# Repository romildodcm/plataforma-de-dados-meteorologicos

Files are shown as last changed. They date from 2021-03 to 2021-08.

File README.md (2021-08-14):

# PLATAFORMA DE DADOS METEOROLÓGICOS
Esse projeto tem por objetivo o desenvolvimento de uma plataforma de dados meteorológicos composta por estações meteorológicas, banco de dados e interface gráfica para análise e monitoramento. Espera-se com esse trabalho formar uma base de dados que permitirá a elaboração de estudos e previsão de geração de energia solar que podem ser aplicados para verificar a viabilidade de instalação de usinas solares, essa plataforma também poderá ser instalada junto de uma unidade geradora para auxiliar no monitoramento de geração, previsões e auxílio na tomada de decisões. Por se tratar de um projeto open source, almeja-se também contribuir com a redução de obstáculos e custos para disseminação e divulgação tecnológica desse tipo de tecnologia.

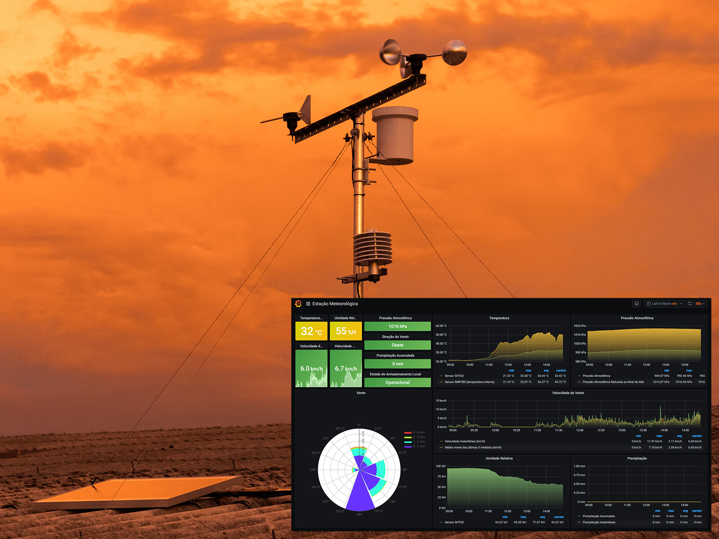
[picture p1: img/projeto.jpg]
Projeto


## ESTAÇÃO METEOROLÓGICA
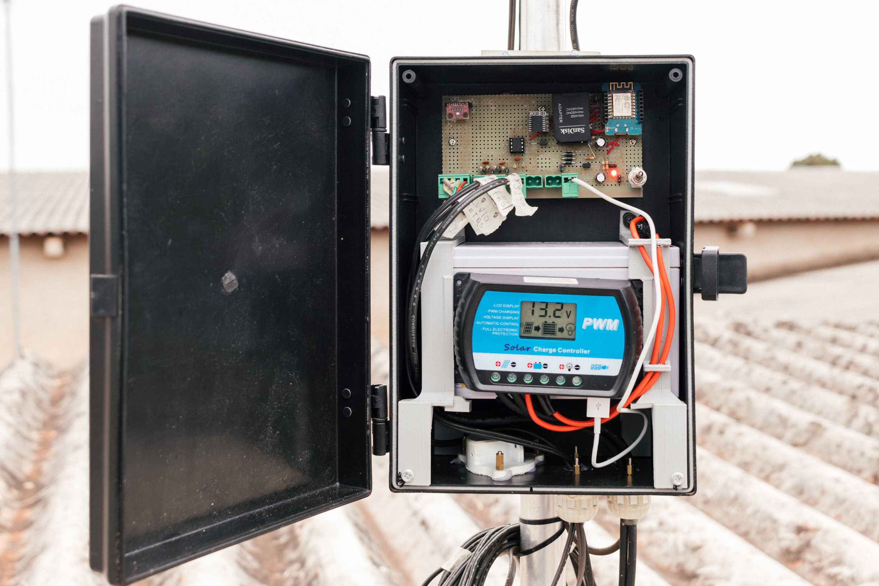
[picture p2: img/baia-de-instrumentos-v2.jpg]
Baia de instrumentação

Seguindo os conceitos de sensor autônomo e internet das coisas (IoT), foi projetada e construída uma estação meteorológica com microcontrolador ESP8266, programado em C/C++® no ambiente Arduino®, e inicialmente com os sensores de direção do vento, temperatura, umidade, pressão, pluviômetro e anemômetro, posteriormente serão implementados sensores de radiação solar direta e global, através de comunicação serial também é possível a implementação de sensores para monitorar a geração de energia, a estação processa os dados desses sensores, envia para internet através de conexão Wi-Fi® e também armazena localmente em cartão de memória.

Os esquemas elétricos para montagem da estação podem ser acessados no diretório *esquema-eletrico* e os códigos para os microcontroladores estão no diretório *software*, no projeto o circuito foi confeccionado usando uma placa ilhada, abaixo estão as tabelas com materiais necessários, esses sistemas foram integrados e montados na estrutura da estação, como pode ser visto nas imagens, os arquivos com as peças e montagem com o programa *Inventor* estão no diretório *estruturas*, também devem ser inseridos em breve os arquivos do projeto/desenhos técnicos em outros formatos.

Tabela 1: Lista de componentes eletrônicos e alojamentos da Estação Meteorológica.
Quantidade | Componente | Valor unitário (R$)
------------ | ------------- | -------------
1 | Bateria Estacionária 7Ah | 109,90
1 | Painel Solar Fotovoltaico 30W | 189,00
1 | Controlador de Carga RTD1230 30A 12/24V | 170,00
2 | Conector MC4 Painel Solar | 10,00
2 | Metro cabo 4 mm² | 5,00
1 | Metro fio 2,5 mm² flexível | 2,00
3 | Metro Cabo flexível 26 AWG | 0,37
1 | Caixa Plástica PB-255/2 | 79,90
1 | Pluviômetro | 344,61
1 | Indicador de direção do vento | 284,63
1 | Anemômetro | 263,970
1 | Sensor de temperatura e umidade SHT20 | 297,23
1 | Alojamento para sensor e temperatura e umidade | 250,74
1 | RTC DS3231 | 22,50
1 | Sensor de pressão e temperatura BMP280 | 14,90
4 | Diodo 1N4007 | 0,10
4 | Borne Conector F 2EDGK-5,0 - 2 Vias | 1,99
1 | Borne Conector F 2EDGK-5,0 - 4 Vias | 3,70
4 | Borne Conector M 2EDGVC-5,0 4P 180º | 1,75
1 | Wemos ESP8266 | 50,00
1 | ATtiny85 DIP8 | 17,00
1 | Soquete DIP8 | 3,00
1 | Mini chave HH Alavanca SMTS102 2 Posições | 2,70
1 | Barra de Pinos 40 vias 11,2mm 180 graus | 1,00
1 | Barra de soquete header fêmea 40 vias 180 graus | 1,65
1 | Cartão microSD com adaptador SD 8GB | 29,9
2 | Capacitor eletrolítico 470uF | 0,50
5 | Capacitor cerâmico 100nF | 0,10
1 | Resistor 220 Ohm 1/4W | 0,10
2 | Resistor 330 Ohm 1/4W | 0,10
2 | Resistor 1k Ohm 1/4W | 0,10
1 | Resistor 10k Ohm 1/4W | 0,10
1 | Resistor 47k Ohm 1/4W | 0,10
1 | Placa padrão tipo ilha 10x15 mm | 14,00
1 | Peças impressas em 3D | 50,00

Tabela 2: Lista de componentes da estrutura da estação meteorológica*.
Quantidade | Componente | Valor unitário (R$)
------------ | ------------- | -------------
1 | 2,5m Tubo redondo alumínio 1.1/4" X 1/16" (31,75mm X 1,58mm) | 39,00
1 | 3m Tubo quadrado alumínio 3/4 X 1/16 (1,9cm X 1,58mm) | 25,00
1 | Chapa de aço 2mmx80x60mm | 5,00
1 | Haste De Cobre Puro 10 mm X 500 mm | 50,00
1 | Borracha espessura 1x80x20mm | 5,00
3 | Espaçador m3 x 15mm | 0,30
7 | Parafuso m3 x 15mm | 0,12
7 | Parafuso m3 x 6mm | 0,10
1 | Parafuso m5 x 16mm | 0,20
2 | Barra roscada 1/4 x 100mm | 2,50
2 | Parafuso sextavado 1/4 x 16mm | 0,30
2 | Parafuso sextavado 1/4 x 30mm | 0,30
24 | Porca sextavada 1/4 | 0,10
20 | Ruela de metal m6 ou 1/4| 0,15
2 | Ruela de metal m3 | 0,10
4 | Ruela de borracha m6 ou 1/4 | 0,25
2 | Anel de borracha m6 | 0,15
6 | Abraçadeira U Vergalhão bitola 1 polegada 80mm rosca 1 quarto (Part. 0070.1) | 6,00
4 | Abraçadeira suporte (Part. 0070.2) | 4,10

***Observações**:
* Na lista e no projeto não estão inclusos estrutura para fixação do painel solar, essa pode ser construída ou comprada, variando de acordo com o tipo de instalação, como pode ser visto na imagem, aqui ela foi fixada em uma cantoneira metálica e essa foi parafusada sobre a cobertura da casa;
* Essa lista é uma base que bate com o projeto disponibilizado no diretório de *estruturas*, podendo/devendo ser alterado em função do local de instalação e conforme os sensores que serão implementados, como se pode notar ao comparar a estação do projeto e a que foi montada, como a que está construída está sobre uma casa onde não precisa de para-raios (já tem em outra estrutura nas proximidades), e também ainda não foram implementados sensores solares, então a estrutura ficou mais simples, para economizar, também podem construir utilizando sucatas;
* Como pode ser visto na imagem a seguir, à esquerda o número 1 indica haste adicionada ao projeto para instalação de sensores solares, na estação construída (à direita) não tem essa haste pois esses sensores ainda não ficaram prontos para serem implementados. Outro detalhe são o uso das barras roscadas que aparecem no projeto e na estação montada, elas servem para prender e regular os fios que fixam e mantem o posicionamento da estação.

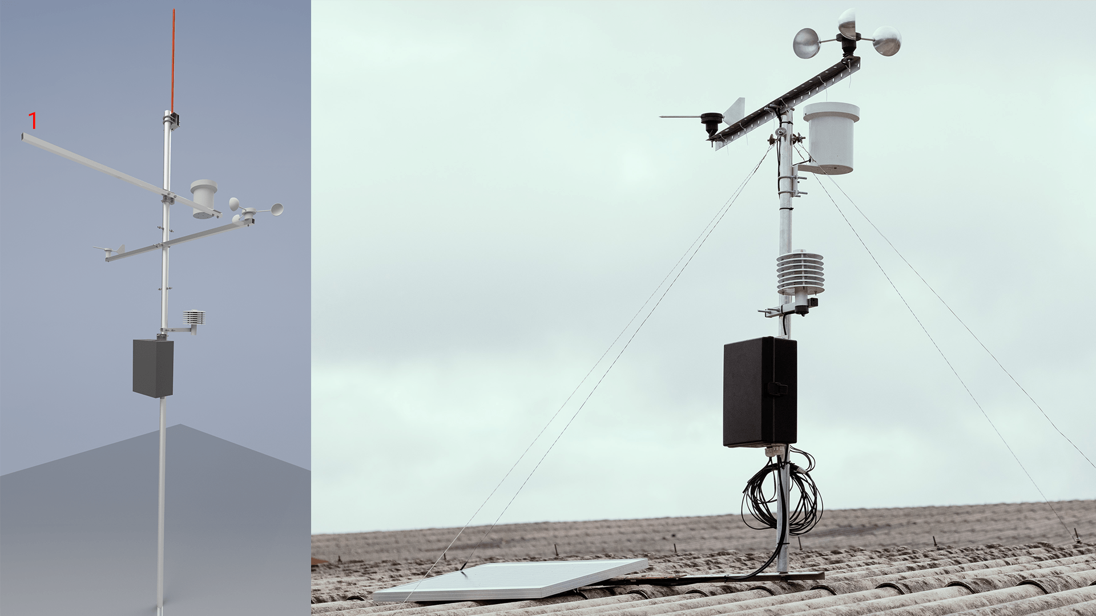
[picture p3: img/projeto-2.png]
Projeto


## BANCO DE DADOS E INTERFACE GRÁFICA

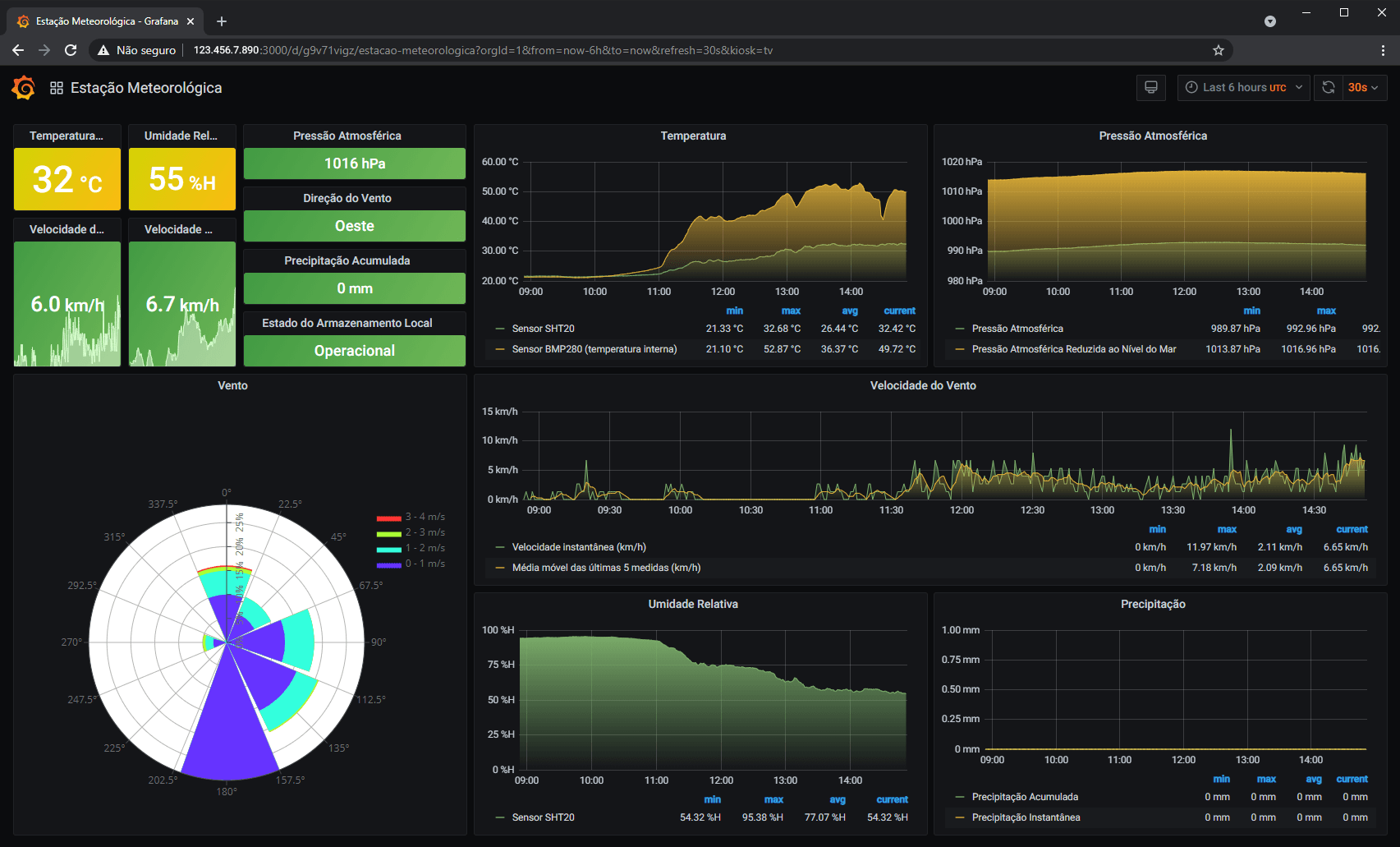
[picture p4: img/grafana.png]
Dashboard Grafana


O banco de dados e a interface de usuário foram implementados em um Raspberry Pi® utilizado como servidor, onde um algoritmo em Python® faz o recebimento e processamento dos dados que são colocados em banco InfluxDB®, nesse servidor foi implementada com Grafana® uma interface gráfica que é acessada por usuários através de um navegador web, sendo apresentados os parâmetros atualizados e séries temporais, como mostra a figura acima. No diretório *weather-station-server-side* é possível ver o script implementado e a documentação que apresenta como fazer a implementação dessa parte do projeto.

Tabela 3: Lista de Materiais para o Servidor.
Quantidade | Componente | Valor unitário (R$)
------------ | ------------- | -------------
1 | Raspberry Pi 4 Model B 4GB | 640,00
1 | Fonte para Raspberry Pi 4 | 65,00
1 | Cartão de memória classe 10 16GB | 60,00

## Descrição das Medidas/Parâmetros/Dados
Para os códigos e hardware dessa versão da estação (v2), temos a estação armazenando localmente, em um arquivo por dia, em horário UTC, a seguinte string com dados separados por vírgula (CSV):

    20210811155149,37.17,99830.05,19.43,63.45,E,3.99,1.00,snr,snr

Contendo 10 parâmetros, sendo 1 de tempo e 9 medidas, após armazenar localmente esses parâmetros, a estação meteorológica concatena um parâmetro a mais que é o status da gravação local, um número inteiro que pode ser 1, 2 ou 3, que respectivamente significam "ok, armazenamento local operacional", "não conseguiu iniciar o cartão de memória e consequentemente não armazenou os dados localmente", "iniciou o cartão de memória, mas não conseguiu armazenar os dados". A string com 11 dados separados por vírgula e transmitida por MQTT é como o exemplo a seguir:

    20210811155149,37.17,99830.05,19.43,63.45,E,3.99,1.00,snr,snr,1

Tabela 1: Descrição dos dados.
Dado | Microcontrolador | Sensor | Posição no CSV | Nome no banco de dados | Tipo no banco de dados | Unidade de medida no CSV | Unidade de medida no Banco de dados | Observação
------------ | ------------- | ------------- | ------------- | ------------- | ------------- | ------------- | ------------- | -------------
Data e Horário da medida | ESP8266 | ---- | 1 | ---- | ---- | ---- | ---- | No CSV está no formato AAAAMMDDhhmmss*
Temperatura | ESP8266 | BMP280 | 2 | temperature_bmp | float | °C | °C | ----
Pressão | ESP8266 | BMP280 | 3 | pressure_bmp | float | Pa | hPa | ----
Temperatura | ESP8266 | SHT20 | 4 | temperature_sht | float | °C | °C | ----
Umidade | ESP8266 | SHT20 | 5 | humidity_sht | float | %H | %H | ----
Direção do Vento | ATtiny85 | Wind Vane | 6 | wind_direction | int | Direção em ponto cardeal | Direção em graus | ----
Velocidade do vento | ATtiny85 | Anemômetro | 7 | anemometer | float | Km/h | Km/h | ----
Precipitação | ATtiny85 | Pluviômetro | 8 | pluviometer_raw | float | mm | mm | ----
Sensor Solar 1 | ATtiny85 Solar | ---- | 9 | serial_sensor1 | int | ---- | ---- | ----
Sensor Solar 2 | ATtiny85 Solar | ---- | 10 | serial_sensor2 | int | ---- | ---- | ----
Status memória SD | ESP8266 | ---- | 11 | sd_memory_status | int | ---- | ---- | 1 = Ok, 2 = erro em SD begin, 3 = erro na escrita de dados

\* **Descrição do formato de data e horário no CSV**
AAAA = ano, quatro dígitos
MM = mês, dois dígitos
DD = dia, dois dígitos
hh = hora, dois dígitos 0 até 24
mm = minutos, dois dígitos
ss = segundos, dois dígitos

\* **Serial Not Received ("snr")**
Quanto o ESP8266 solicita os dados e eles não são recebidos ou chegam danificados, então é retornado esse valor ```snr```, e quando esse valor chega no script em Python, ele é interpretado como null, portanto não é armazenado essa medida no banco de dados.

## Recomendações para futuras implementações
#### API para acesso aos dados
Hoje o acesso aos dados pode ser feito acessando diretamente o banco de dados InfluxDB ou via Grafana, mas seria interessante posteriormente ser desenvolvida uma API onde sejam cadastrados usuários e esses cadastrados possam fazer o acesso aos dados dentro de parâmetros específicos, etc, permitindo automação do processamento de dados ou estudos com scripts.

#### Interface gráfica publica
Se tiver servidor/VPS pode ser implementada alguma interface, página web, aberta em que as pessoas possam acessar e visualizar os dados, por exemplo, das últimas 24h, talvez isso pode ser feito com Grafana, tornando o acesso para visualização público, ou deixando publico um usuário e senha sem permissões administrativas, para apenas visualização ou tentar as opções de [share a dashboard](https://grafana.com/docs/grafana/latest/sharing/share-dashboard/).

#### Segurança
**Implementar Backup** das informações que hoje estão no cartão de memória do Raspberry Pi, que se queimar, todas as informações são perdidas.
Implementar **recursos de segurança** como HTTPs, criptografias e demais recursos que algum profissional da área ou usuário possam recomendar.

#### Sleep Time no ESP8266

No final do código esp8266.ino tem uma linha com a seguinte operação: ```sleep_time = abs(59000 - sleep_time);```, é recomendado, para evitar passar o limite de tráfego do MQTT em possível sincronização das estações,  variar o valor do ```59000``` para cada estação adicionada, para a estação 1 foi deixado em ```60000```, a estação 2 em ```59000```.

## EQUIPE E CONTATO

Esse projeto foi desenvolvido por Romildo C Marques¹, quando aluno de engenharia física (UNILA), sendo orientado pelo prof. Oswaldo Hideo Ando Junior² (GPEnSE) da Universidade Federal da Integração Latino-Americana (UNILA).

Contato¹: romildodcm@gmail.com
Contato²: oswaldo.junior@unila.edu.br

## APOIO E FOMENTO

Este projeto foi desenvolvido com apoio e fomento de:
* Conselho Nacional de Desenvolvimento Científico e Tecnológico - CNPq;
* Universidade Federal da Integração Latino-Americana (UNILA);
* Grupo de Pesquisa em Energia e Sustentabilidade Energética - GPEnSE;
* Programa Agenda Tríplice da UNILA pelo apoio e fomento à pesquisa.

## AGRADECIMENTOS
Aos amigos e familiares pelo apoio;
Ao professor Oswaldo Hideo Ando Junior pela orientação;
Ao professor Joylan Nunes Maciel por auxíliar com banco de dados;
Ao Lucas Teske (@racerxdl) que apresentou e recomendou as tecnologias InfluxDB e Grafana.



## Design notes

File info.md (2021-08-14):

# Configuração para gravação do ATtiny85

Para a gravação de código no ATtiny85 é necessário remover ele da placa da estação meteorológica e usar um Arduino como placa gravadora, além disso é necessário configurar a IDE Arduino instalando a placa e selecionando as opções corretas antes de enviar o código, abaixo estão as configurações utilizadas e em seguida alguns links de referência.

Configuração da IDE Arduino para compilação e envio de código para ATtiny85
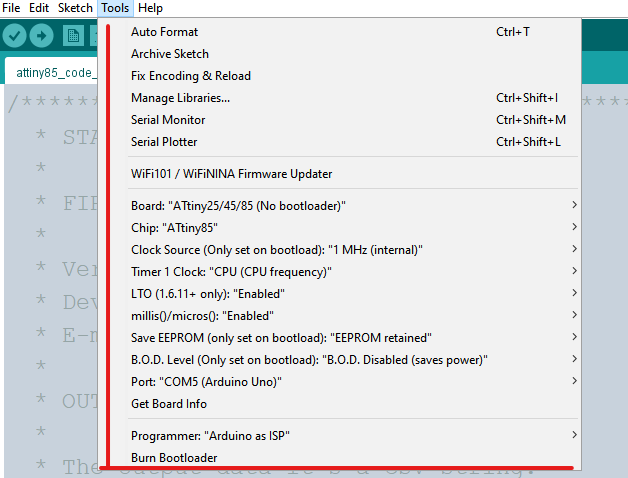
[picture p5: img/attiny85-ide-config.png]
Configuração da IDE para gravação do microcontrolador ATtiny85

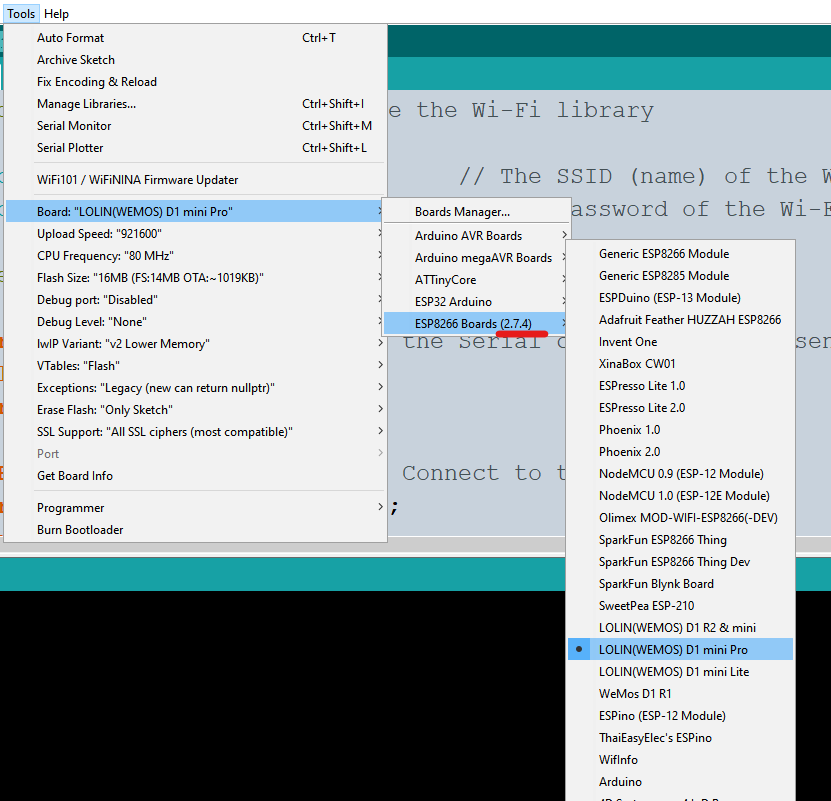
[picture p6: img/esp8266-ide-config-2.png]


[Como Gravar um Attiny85 usando um Arduino Nano](https://youtu.be/0S3D9iLHu5w)
[Programar o ATtiny85 com Arduino: como funciona](https://br-arduino.org/2015/01/programar-o-attiny85-com-arduino-como-funciona.html)
[Como gravar o bootloader do ATtiny85 com Arduino](https://www.arduinoecia.com.br/gravar-bootloader-attiny85-arduino-uno/)

# Configuração para gravação do ESP8266

O ESP8266, usado na estação meteorológica como placa de desenvolvimento WEMOS, para ser programado com IDE Arduino é necessário configurar a IDE instalando a placa e selecionando as opções corretas antes de enviar o código, abaixo estão as configurações utilizadas e em seguida alguns links de referência. Esse código foi compilado tendo a versão 2.7 das placas adicionadas na IDE do Arduino, com versões mais recentes teve erro, na hora da instalação da palca é possível selecionar a versão na IDE Arduino [veja mais](https://www.filipeflop.com/blog/programar-nodemcu-com-ide-arduino/).

Configuração da IDE Arduino para compilação e envio de código para ESP8266 (WEMOS Dev Board)
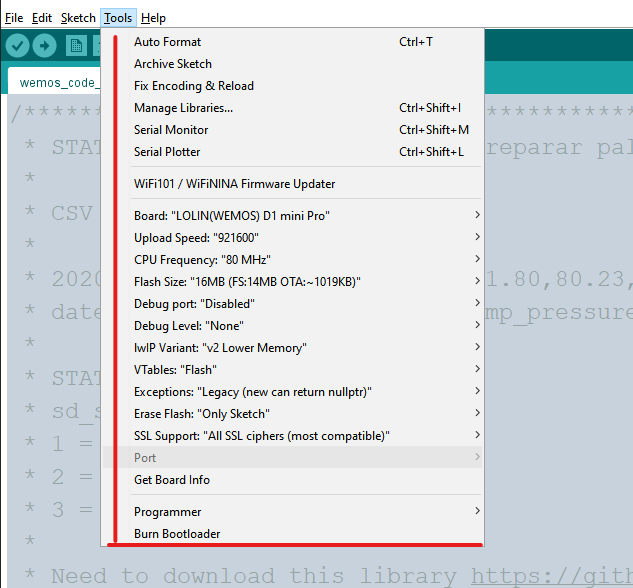
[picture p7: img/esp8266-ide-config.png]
Configuração da IDE para gravação do microcontrolador ESP8266


[Configurar Arduino IDE com ESP8266 e Blynk (HomeLab)](https://edisciplinas.usp.br/pluginfile.php/6231574/mod_resource/content/3/Configurar%20Arduino%20IDE%20com%20ESP8266%20e%20Blynk%20%28HomeLab%29.pdf)
[Conheça o Wemos D1 Mini: pequena no tamanho e imensa nas funcionalidades](https://blogmasterwalkershop.com.br/embarcados/wemos/conheca-wemos-d1-mini)

# Diretórios

Na pasta de hardware tem os projetos em 3D e peças da estação meteorológica, e também projeto de placa controladora e esquema/circuito elétrico, na pasta de software estão os códigos que estão gravados nos microcontroladores das estações meteorológicas. Na pasta attiny85-solar tem um código base para rodas nos microcontroladores dos sensores solares, esse código foi testado com o ATtiny85 conectado na estação e enviando dois números inteiros aleatórios (simulando leitura analógica) para a estação, que recebia esses parâmetros e envia para o servidor.

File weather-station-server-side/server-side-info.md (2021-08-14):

# Configuração Script, InfluxDB e Grafana

## Índice
- [Introdução](#introducao)
- [Configuração de reserva de endereço de IP via DHCP (servidor local)](#ip)
- [Instalação e configuração de banco de dados InfluxDB 1.8](#influx)
- [Instalação e configuração do Grafana](#grafana)
- [MQTT](#MQTT)

## Introdução

Essa parte da plataforma de dados meteorológicos deve ser implementada em servidor, que pode ser desde um Raspberry Pi (a partir da versão 3b) até um serviço VPS, sendo responsável pelas etapas que vão desde a recepção dos dados meteorológicos via MQTT até o armazenamento no banco de dados e disponibilização de interface gráfica ao usuário.

Para a implementação dessa etapa é interessante ter o conhecimento básico de redes, sistemas Unix/Linux, uso de terminal via SSH e linguagem Python, pois as implementações estão divididas em:

- Configuração de reserva de endereço de IP via DHCP (servidor local);
- Instalação e configuração de banco de dados InfluxDB 1.8;
- Configuração de parâmetros para o script Python e Crontab;
- Instalação e configuração do Grafana.

## Configuração de reserva de endereço de IP via DHCP (servidor local)

Ao completar a instalação do banco de dados, o mesmo deverá ser acessado através de um endereço de IP para armazenamento e requisições das informações meteorológicas, se estiver usando um Raspberry Pi em sua rede local, o seu modem pode dar endereços IP aleatórios ao Raspberry, para evitar isso é necessário que identifique o endereço MAC do seu Raspberry Pi, que pode estar na caixa dele ou então pode ser visto usando o comando *ifconfig* no terminal, o Raspberry Pi tem um endereço MAC para o Wi-Fi e outro para a conexão cabeada, então use o endereço MAC do tipo de conexão que estiver sendo utilizada. Com o endereço MAC, acesse a página de configuração de seu modem/roteador e vá até a opção de **DHCP Server** ou nome semelhante, nessa opção procure por **Address Reservation**, **Reserva de Endereço** ou nome semelhante, nessa opção você vai adicionar o endereço MAC do Raspberry Pi e reservar um endereço de IP para ele, reinicie o modem e o Raspberry para implementar a reserva de endereço, anote o IP escolhido, pois ele é um dos parâmetros necessários para o script em Python e também para o Grafana.

## Instalação e configuração de banco de dados InfluxDB 1.8

Esse projeto foi implementado com o banco de dados InfluxDB, para instalar esse banco de dados, acesse https://portal.influxdata.com/downloads/, instale também o influxdb-client com o comando *udo apt install influxdb-client*. Para saber mais sobre o uso do InfluxDB e uma base de como funciona a integração entre Python e InfluxDB, e também sobre a configuração do Grafana, veja a publicação disponível em https://diyi0t.com/visualize-mqtt-data-with-influxdb-and-grafana/, vale lembrar que a instalação do influxDB apresentada nesse segundo link não garante que será a versão 1.8 (necessária para ser compatível com o script python).

Nessa etapa, o nome padrão escolhido para o banco de dados foi **weather_stations_data**, também foi criado um usuário **putdata** para adicionar dados com o script em Python e o **getdata** que será utilizado pelo Grafana para solicitar dados. Caso escolha nomes diferentes, implemente as alterações nas próximas etapas, mudando isso no arquivo [**.env**](./.env) e no **Grafana**.

Para implementar atualizações, gerenciar o banco de dados, etc, verifique a documentação em [InfluxDB OSS 1.8 Documentation](https://docs.influxdata.com/influxdb/v1.8/).

## Configuração de parâmetros para o script Python e Crontab

O script em Python 3 é responsável por receber os dados via MQTT, processar eles e armazenar no banco de dados, para ele ser executado é necessário ter instaladas as bibliotecas que estão citadas nas primeiras linhas de [**script.py**](./script.py) e também ter no mesmo diretório o [**weather_station.py**](./weather_station.py) e o arquivo [**.env**](./.env) com parâmetros de configuração.

Em [**script.py**](./script.py) está o básico do programa, como receber os dados, fazer uma breve verificação e passar para as funções do [**weather_station.py**](./weather_station.py), que farão o resto do processamento e retornarão uma lista de dicionários, compatíveis com o tipo JSON, e esta é enviada para o banco de dados. As senhas, e o endereço de IP do banco de dados no Raspberry Pi/Servidor, credenciais do banco de dado e MQTT devem ser inseridas no arquivo [**.env**](./.env), esses trÊs arquivos estando na mesma pasta, já é possível executar para testes, durante a execução o programa retorna as saídas abaixo:

```
MQTT to InfluxDB script
Connected with result code 0
--------------------------------------------------------------------------------------------------------------------------------
Measurement time: 2021-08-04T14:43:08Z
Weather station: ws01
Message length: 11
Received data: 20210804144308,40.47,100230.45,21.88,44.03,E,2.66,0.00,snr,snr,1
Invalid serial_sensor1: snr => null
Invalid serial_sensor2: snr => null
Writing to database...
{'measurement': 'temperature_bmp', 'tags': {'location': 'ws01'}, 'time': '2021-08-04T14:43:08Z', 'fields': {'value': 40.47}}
{'measurement': 'pressure_bmp', 'tags': {'location': 'ws01'}, 'time': '2021-08-04T14:43:08Z', 'fields': {'value': 1002.3045}}
{'measurement': 'temperature_sht', 'tags': {'location': 'ws01'}, 'time': '2021-08-04T14:43:08Z', 'fields': {'value': 21.88}}
{'measurement': 'humidity_sht', 'tags': {'location': 'ws01'}, 'time': '2021-08-04T14:43:08Z', 'fields': {'value': 44.03}}
{'measurement': 'wind_direction', 'tags': {'location': 'ws01'}, 'time': '2021-08-04T14:43:08Z', 'fields': {'value': 90}}
{'measurement': 'anemometer', 'tags': {'location': 'ws01'}, 'time': '2021-08-04T14:43:08Z', 'fields': {'value': 2.66}}
{'measurement': 'pluviometer_raw', 'tags': {'location': 'ws01'}, 'time': '2021-08-04T14:43:08Z', 'fields': {'value': 0.0}}
{'measurement': 'sd_memory_status', 'tags': {'location': 'ws01'}, 'time': '2021-08-04T14:43:08Z', 'fields': {'value': 1}}
Status write data to Influx Database: True
--------------------------------------------------------------------------------------------------------------------------------
Measurement time: 2021-08-04T14:43:15Z
Weather station: ws_test
Message length: 11
Received data: 20210804144315,36.58,100283.08,31.86,31.66,SE,2.66,1.75,snr,snr,1
Invalid serial_sensor1: snr => null
Invalid serial_sensor2: snr => null
Writing to database...
{'measurement': 'temperature_bmp', 'tags': {'location': 'ws_test'}, 'time': '2021-08-04T14:43:15Z', 'fields': {'value': 36.58}}
{'measurement': 'pressure_bmp', 'tags': {'location': 'ws_test'}, 'time': '2021-08-04T14:43:15Z', 'fields': {'value': 1002.8308}}
{'measurement': 'temperature_sht', 'tags': {'location': 'ws_test'}, 'time': '2021-08-04T14:43:15Z', 'fields': {'value': 31.86}}
{'measurement': 'humidity_sht', 'tags': {'location': 'ws_test'}, 'time': '2021-08-04T14:43:15Z', 'fields': {'value': 31.66}}
{'measurement': 'wind_direction', 'tags': {'location': 'ws_test'}, 'time': '2021-08-04T14:43:15Z', 'fields': {'value': 135}}
{'measurement': 'anemometer', 'tags': {'location': 'ws_test'}, 'time': '2021-08-04T14:43:15Z', 'fields': {'value': 2.66}}
{'measurement': 'pluviometer_raw', 'tags': {'location': 'ws_test'}, 'time': '2021-08-04T14:43:15Z', 'fields': {'value': 1.75}}
{'measurement': 'sd_memory_status', 'tags': {'location': 'ws_test'}, 'time': '2021-08-04T14:43:15Z', 'fields': {'value': 1}}
Status write data to Influx Database: True

```

Perceba as linhas alertando para valores inválidos 'Invalid serial_sensor1: snr => null', isso é porque o código está preparado para receber valores de sensores solares que atualmente não estão conectados nas estações, estes serão os serial_sensor1 e serial_sensor2 que por estarem desconectados a estação manda apenas um código 'snr' (serial not received), que o script em python identifica e então não armazena os valores.

Para que esse script seja iniciado automaticamente após o Raspberry Pi o servidor ser reiniciado ou sofrer alguma interrupção, é necessário configurar o [Crontab](https://www.raspberrypi.org/blog/how-to-run-a-script-at-start-up-on-a-raspberry-pi-using-crontab/), para isso siga os comandos abaixo no terminal/SSH do Raspberry Pi, caso for servidor os comandos ou diretórios serão diferentes.

```
cd /home/pi
mkdir weather-station-server-side
cd weather-station-server-side
mkdir logs
nano launcher.sh
```
Após o último comando abrirá o editor nano, cole nele o conteúdo do arquivo **launcher.sh** e feche com ctrl + x. Em seguida tecle o comando `sudo crontab -e`, abrirá um arquivo, após as linhas de instruções adicione a instrução a seguir e tecle ctrl + x: `@reboot sh /home/pi/weather-station-server-side/launcher.sh >/home/pi/weather-station-server-side/logs/cronlog 2>&1`

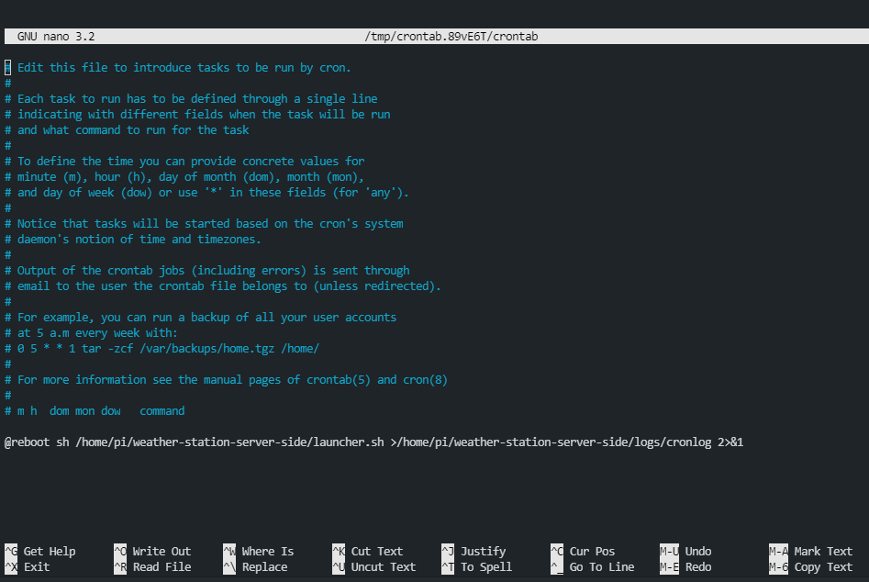
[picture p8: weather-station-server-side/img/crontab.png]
Crontab


Após executar essas configurações, reinicie o Raspberry Pi, na pasta logs terá um arquivo onde ficarão os logs do script. No artigo [Visualize MQTT Data with InfluxDB and Grafana](https://diyi0t.com/visualize-mqtt-data-with-influxdb-and-grafana/) o autor também apresenta sobre o crontab. 

## Instalação e configuração do Grafana
Grafana

Em [Visualize MQTT Data with InfluxDB and Grafana](https://diyi0t.com/visualize-mqtt-data-with-influxdb-and-grafana/), na seção 4 *Grafana Setup to Visualize Data from InfluxDB* tem o procedimento básico de instalação e configuração. Além das configurações básicas (usuários, conexão com banco de dados, etc) é preciso adicionar a dashboards, para ter uma igual a que é apresentada na imagem acima, instale o plugin [Windrose Panel for Grafana](https://github.com/fatcloud/windrose-panel) e em seguida acesse a interface do Grafana através do navegador, clique no ícone para adicionar uma dashboard e clique em importar (1), depois clique e **Upload JSON file** (2) e importe o arquivo [**grafana-dashboard-model.json**](./grafana-dashboard-model.json) que está nesse diretório, para finalizar clique em **Import** (3), como apresentam as imagens abaixo.

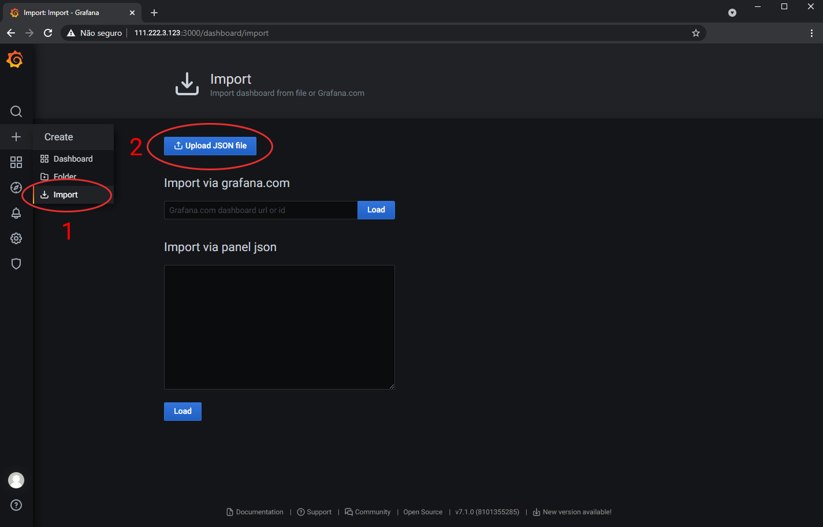
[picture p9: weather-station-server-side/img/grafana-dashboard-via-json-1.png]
Add via json 1

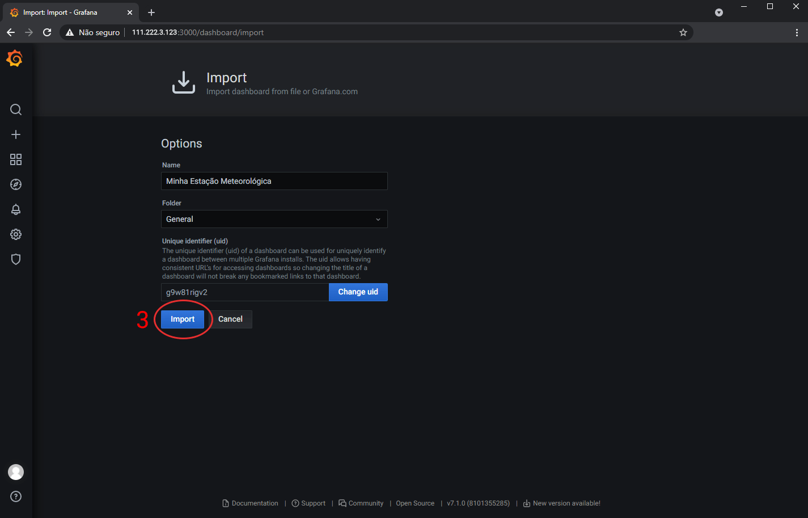
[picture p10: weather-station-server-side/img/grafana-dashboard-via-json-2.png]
Add via json 2


Observação: a base/banco de dados **weather_stations_data** deverá ser configurada como padrão/default no grafana.

## MQTT

Nesse projeto foi utilizado o serviço de cloudmqtt.com, caso optar por não adquirir um serviço e queira fazer seu próprio servidor MQTT, é possível ver o passo a passo na seção *Setup the MQTT Broker to Receive MQTT Data (Raspberry Pi)*, da publicação [Send data from ESP8266 or ESP32 to Raspberry Pi via MQTT](https://diyi0t.com/microcontroller-to-raspberry-pi-wifi-mqtt-communication/).

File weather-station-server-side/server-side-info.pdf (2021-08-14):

# Configuração Script, InfluxDB e Grafana

# Índice

Introdução
Configuração de reserva de endereço de IP via DHCP (servidor local) Instalação e configuração de banco de dados InfluxDB 1.8 Instalação e configuração do Grafana
MQTT

# Introdução

Essa parte da plataforma de dados meteorológicos deve ser implementada em servidor, que pode ser desde um Raspberry Pi (a partir da versão 3b) até um serviço VPS, sendo responsável pelas etapas que vão desde a recepção dos dados meteorológicos via MQTT até o armazenamento no banco de dados e disponibilização de interface gráfica ao usuário.

Para a implementação dessa etapa é interessante ter o conhecimento básico de redes, sistemas Unix/Linux, uso de terminal via SSH e linguagem Python, pois as implementações estão divididas em:

Configuração de reserva de endereço de IP via DHCP (servidor local);
Instalação e configuração de banco de dados InfluxDB 1.8;
Configuração de parâmetros para o script Python e Crontab;
Instalação e configuração do Grafana.

# Configuração de reserva de endereço de IP via DHCP (servidor local)

Ao completar a instalação do banco de dados, o mesmo deverá ser acessado através de um endereço de IP para armazenamento e requisições das informações meteorológicas, se estiver usando um Raspberry Pi em sua rede local, o seu modem pode dar endereços IP aleatórios ao Raspberry, para evitar isso é necessário que identifique o endereço MAC do seu Raspberry Pi, que pode estar na caixa dele ou então pode ser visto usando o comando ifconfig no terminal, o Raspberry Pi tem um endereço MAC para o Wi-Fi e outro para a conexão cabeada, então use o endereço MAC do tipo de conexão que estiver sendo utilizada. Com o endereço MAC, acesse a página de configuração de seu modem/roteador e vá até a opção de DHCP Server ou nome semelhante, nessa opção procure por Address Reservation, Reserva de Endereço ou nome semelhante, nessa opção você vai adicionar o endereço MAC do Raspberry Pi e reservar um endereço de IP para ele, reinicie o modem e o Raspberry para implementar a reserva de endereço, anote o IP escolhido, pois ele é um dos parâmetros necessários para o script em Python e também para o Grafana.

# Instalação e configuração de banco de dados InfluxDB 1.8

Esse projeto foi implementado com o banco de dados InfluxDB, para instalar esse banco de dados, acesse https://portal.influxdata.com/downloads/, instale também o influxdb-client com o comando udo apt install influxdb-client. Para saber mais sobre o uso do InfluxDB e uma base de como funciona a integração entre Python e InfluxDB, e também sobre a configuração do Grafana, veja a publicação disponível em https://diyi0t.com/visualize-mqtt-data-with-influxdb-and-grafana/, vale lembrar que a instalação do influxDB apresentada nesse segundo link não garante que será a versão 1.8 (https://diyi0t.com/visualize-mqtt-data-with-influxdb-and-grafana/) (necessária para ser compatível com o script python).

Nessa etapa, o nome padrão escolhido para o banco de dados foi weather_stations_data, também foi criado um usuário putdata para adicionar dados com o script em Python e o getdata que será utilizado pelo Grafana para solicitar dados. Caso escolha nomes diferentes, implemente as alterações nas próximas etapas, mudando isso no arquivo .env e no Grafana.

Para implementar atualizações, gerenciar o banco de dados, etc, verifique a documentação em InfluxDB OSS 1.8 Documentation. (https://docs.influxdata.com/influxdb/v1.8/)

# Configuração de parâmetros para o script Python e Crontab

O script em Python 3 é responsável por receber os dados via MQTT, processar eles e armazenar no banco de dados, para ele ser executado é necessário ter instaladas as bibliotecas que estão citadas nas primeiras linhas de script.py e também ter no mesmo diretório o weather_station.py e o arquivo .env com parâmetros de configuração.

Em script.py está o básico do programa, como receber os dados, fazer uma breve verificação e passar para as funções do weather_station.py, que farão o resto do processamento e retornarão uma lista de dicionários, compatíveis com o tipo JSON, e esta é enviada para o banco de dados. As senhas, e o endereço de IP do banco de dados no Raspberry Pi/Servidor, credenciais do banco de dado e MQTT devem ser inseridas no arquivo .env, esses trÊs arquivos estando na mesma pasta, já é possível executar para testes, durante a execução o programa retorna as saídas abaixo:

MQTT to InfluxDB script
Connected with result code 0 --------------------------------------------------------------------------------------------------------------------------------Measurement time: 2021-08-04T14:43:08Z
Weather station: ws01
Message length: 11
Received data: 20210804144308,40.47,100230.45,21.88,44.03,E,2.66,0.00,snr,snr,1 Invalid serial_sensor1: snr => null
Invalid serial_sensor2: snr => null
Writing to database...
{'measurement': 'temperature_bmp', 'tags': {'location': 'ws01'}, 'time': '2021-08-04T14:43:08Z', 'fields': {'value': 40.47}} {'measurement': 'pressure_bmp', 'tags': {'location': 'ws01'}, 'time': '2021-08-04T14:43:08Z', 'fields': {'value': 1002.3045}} {'measurement': 'temperature_sht', 'tags': {'location': 'ws01'}, 'time': '2021-08-04T14:43:08Z', 'fields': {'value': 21.88}} {'measurement': 'humidity_sht', 'tags': {'location': 'ws01'}, 'time': '2021-08-04T14:43:08Z', 'fields': {'value': 44.03}} {'measurement': 'wind_direction', 'tags': {'location': 'ws01'}, 'time': '2021-08-04T14:43:08Z', 'fields': {'value': 90}} {'measurement': 'anemometer', 'tags': {'location': 'ws01'}, 'time': '2021-08-04T14:43:08Z', 'fields': {'value': 2.66}} {'measurement': 'pluviometer_raw', 'tags': {'location': 'ws01'}, 'time': '2021-08-04T14:43:08Z', 'fields': {'value': 0.0}} {'measurement': 'sd_memory_status', 'tags': {'location': 'ws01'}, 'time': '2021-08-04T14:43:08Z', 'fields': {'value': 1}} Status write data to Influx Database: True --------------------------------------------------------------------------------------------------------------------------------Measurement time: 2021-08-04T14:43:15Z
Weather station: ws_test
Message length: 11
Received data: 20210804144315,36.58,100283.08,31.86,31.66,SE,2.66,1.75,snr,snr,1 Invalid serial_sensor1: snr => null
Invalid serial_sensor2: snr => null
Writing to database...
{'measurement': 'temperature_bmp', 'tags': {'location': 'ws_test'}, 'time': '2021-08-04T14:43:15Z', 'fields': {'value': 36.58}} {'measurement': 'pressure_bmp', 'tags': {'location': 'ws_test'}, 'time': '2021-08-04T14:43:15Z', 'fields': {'value': 1002.8308}} {'measurement': 'temperature_sht', 'tags': {'location': 'ws_test'}, 'time': '2021-08-04T14:43:15Z', 'fields': {'value': 31.86}} {'measurement': 'humidity_sht', 'tags': {'location': 'ws_test'}, 'time': '2021-08-04T14:43:15Z', 'fields': {'value': 31.66}} {'measurement': 'wind_direction', 'tags': {'location': 'ws_test'}, 'time': '2021-08-04T14:43:15Z', 'fields': {'value': 135}} {'measurement': 'anemometer', 'tags': {'location': 'ws_test'}, 'time': '2021-08-04T14:43:15Z', 'fields': {'value': 2.66}} {'measurement': 'pluviometer_raw', 'tags': {'location': 'ws_test'}, 'time': '2021-08-04T14:43:15Z', 'fields': {'value': 1.75}} {'measurement': 'sd_memory_status', 'tags': {'location': 'ws_test'}, 'time': '2021-08-04T14:43:15Z', 'fields': {'value': 1}} Status write data to Influx Database: True

Perceba as linhas alertando para valores inválidos 'Invalid serial_sensor1: snr => null', isso é porque o código está preparado para receber valores de sensores solares que atualmente não estão conectados nas estações, estes serão os serial_sensor1 e serial_sensor2 que por estarem desconectados a estação manda apenas um código 'snr' (serial not received), que o script em python identifica e então não armazena os valores.

Para que esse script seja iniciado automaticamente após o Raspberry Pi o servidor ser reiniciado ou sofrer alguma interrupção, é necessário configurar o Crontab, (https://www.raspberrypi.org/blog/how-to-run-a-script-at-start-up-on-a-raspberry-pi-using-crontab/) para isso siga os comandos abaixo no terminal/SSH do Raspberry Pi, caso for servidor os comandos ou diretórios serão diferentes.

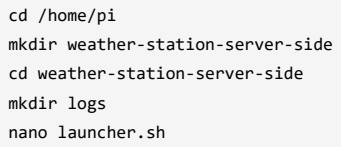
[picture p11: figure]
cd /home/pi mkdir weather-station-server-side cd weather-station-server-side mkdir logs nano launcher.sh

Após o último comando abrirá o editor nano, cole nele o conteúdo do arquivo launcher.sh e feche com ctrl + x. Em seguida tecle o comando sudo crontab -e , abrirá um arquivo, após as linhas de instruções adicione a instrução a seguir e tecle ctrl + x:
@reboot sh /home/pi/weather-station-server-side/launcher.sh >/home/pi/weather-station-server-side/logs/cronlog 2>&1

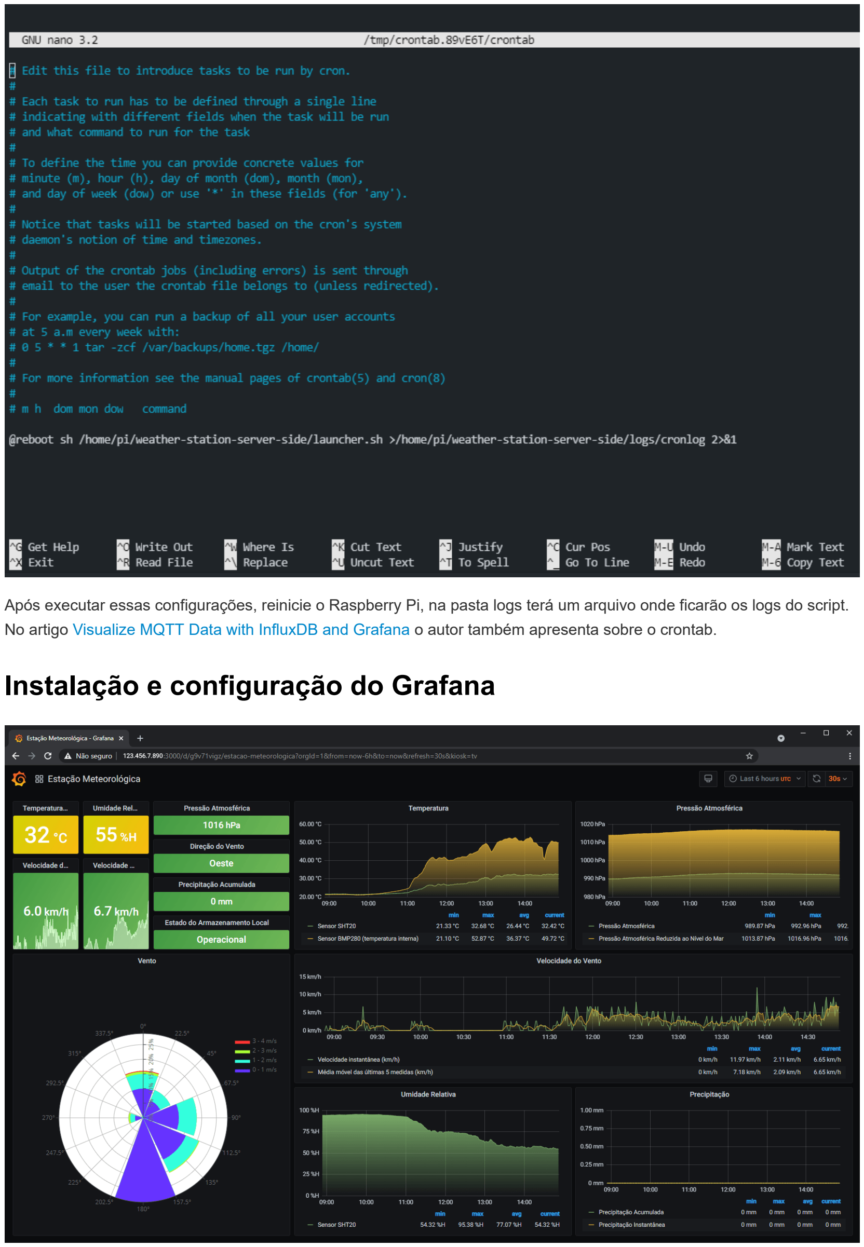
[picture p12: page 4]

Após executar essas configurações, reinicie o Raspberry Pi, na pasta logs terá um arquivo onde ficarão os logs do script. No artigo Visualize MQTT Data with InfluxDB and Grafana (https://diyi0t.com/visualize-mqtt-data-with-influxdb-and-grafana/) o autor também apresenta sobre o crontab.

# Instalação e configuração do Grafana

Em Visualize MQTT Data with InfluxDB and Grafana, (https://diyi0t.com/visualize-mqtt-data-with-influxdb-and-grafana/) na seção 4 Grafana Setup to Visualize Data from InfluxDB tem o procedimento básico de instalação e configuração. Além das configurações básicas (usuários, conexão com banco de dados, etc) é preciso adicionar a dashboards, para ter uma igual a que é apresentada na imagem acima, instale o plugin Windrose Panel for Grafana (https://github.com/fatcloud/windrose-panel) e em seguida acesse a interface do Grafana através do navegador, clique no ícone para adicionar uma dashboard e clique em importar (1), depois clique e Upload JSON file (2) e importe o arquivo grafana-dashboard-model.json que está nesse diretório, para finalizar clique em Import (3), como apresentam as imagens abaixo.



Observação: a base/banco de dados weather_stations_data deverá ser configurada como padrão/default no grafana.

# MQTT

Nesse projeto foi utilizado o serviço de cloudmqtt.com, caso optar por não adquirir um serviço e queira fazer seu próprio servidor MQTT, é possível ver o passo a passo na seção Setup the MQTT Broker to Receive MQTT Data (Raspberry Pi), da publicação Send data from ESP8266 or ESP32 to Raspberry Pi via MQTT. (https://diyi0t.com/microcontroller-to-raspberry-pi-wifi-mqtt-communication/)

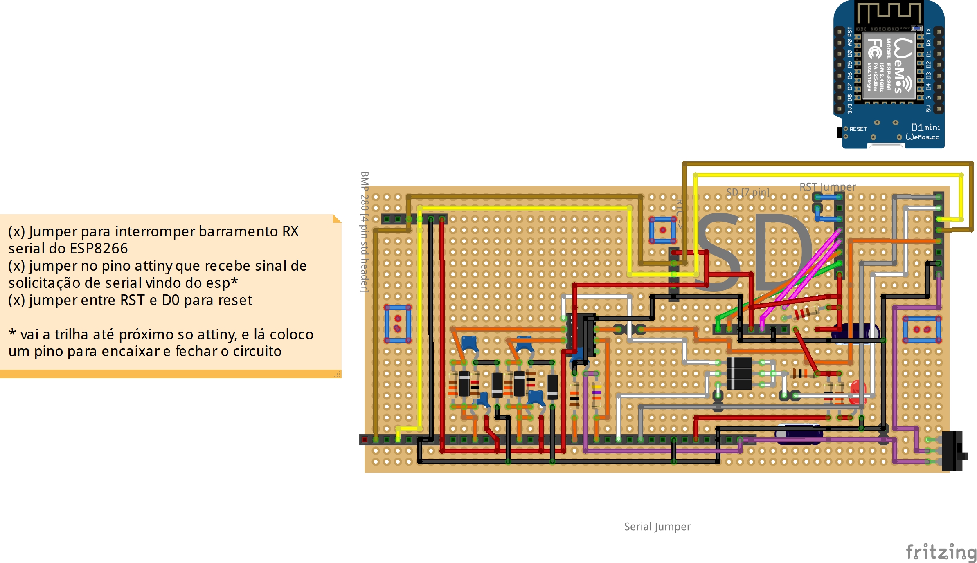
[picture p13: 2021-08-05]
weather-station/hardware/esquema-eletrico/rev 1 - Placa estação 1/Esquema elétrico sistema IT - v4 - RTC - protoboard - Com manutenção_bb.jpg

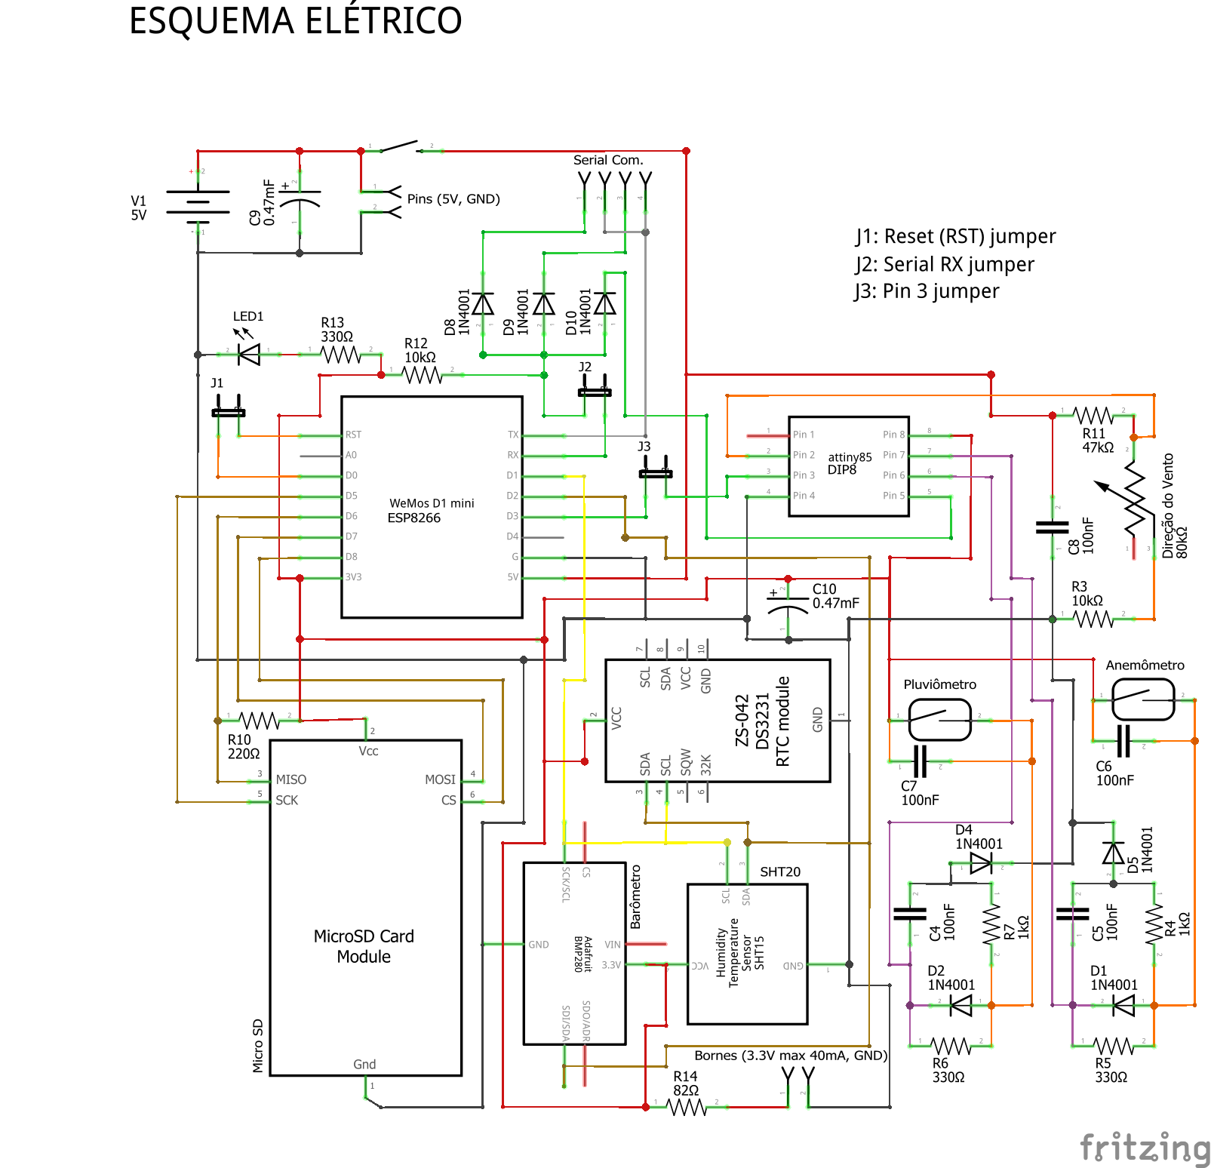
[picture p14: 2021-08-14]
weather-station/hardware/esquema-eletrico/rev3 - placa estação 2/Esquema elétrico estação meteorológica - rev3_Esquemático.png

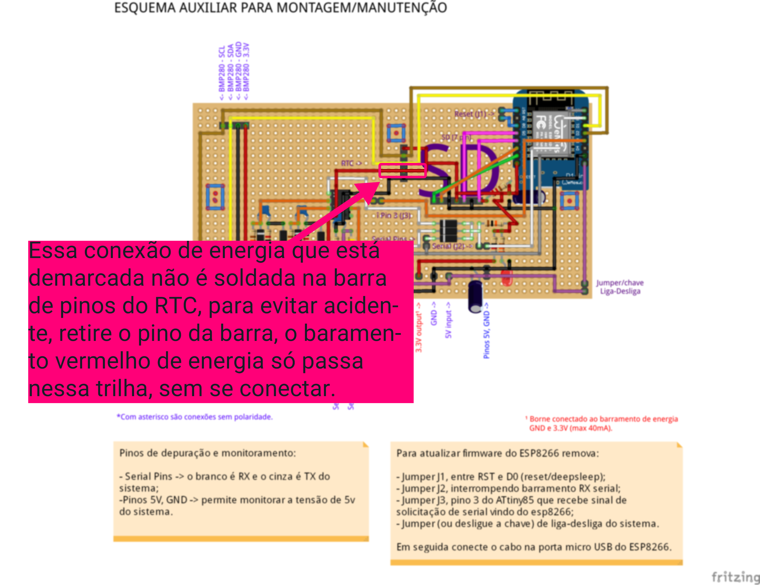
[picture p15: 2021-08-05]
weather-station/hardware/esquema-eletrico/rev 1 - Placa estação 1/0-VEJA ISSO.png

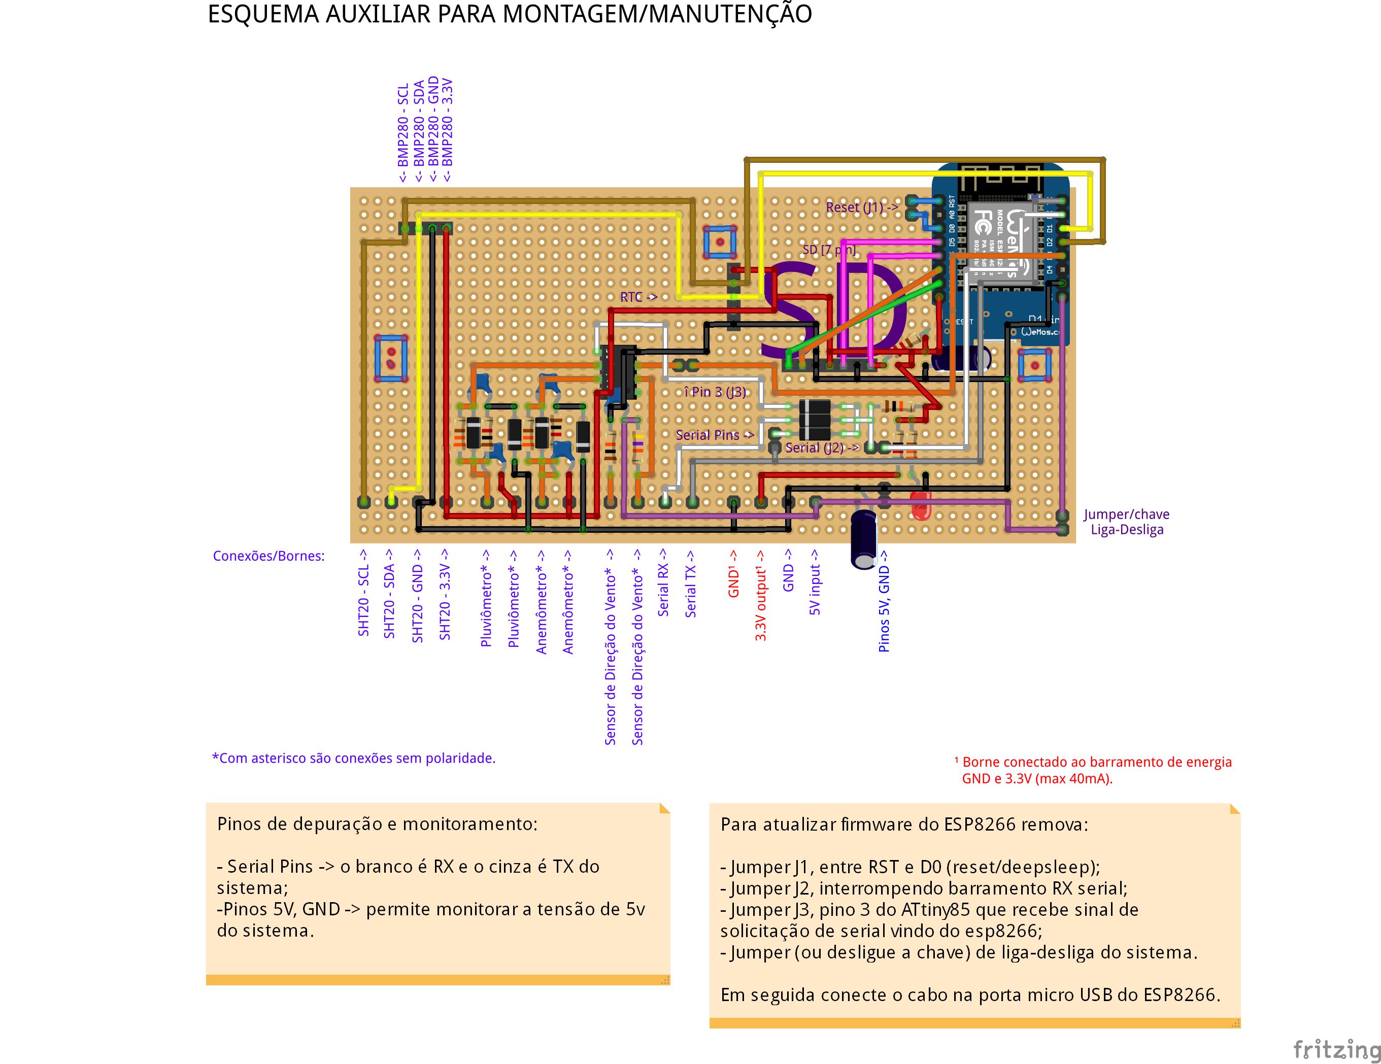
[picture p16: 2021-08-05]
weather-station/hardware/esquema-eletrico/rev 1 - Placa estação 1/Esquema elétrico auxiliar para exemplo de protoboard - rev3_bb.png

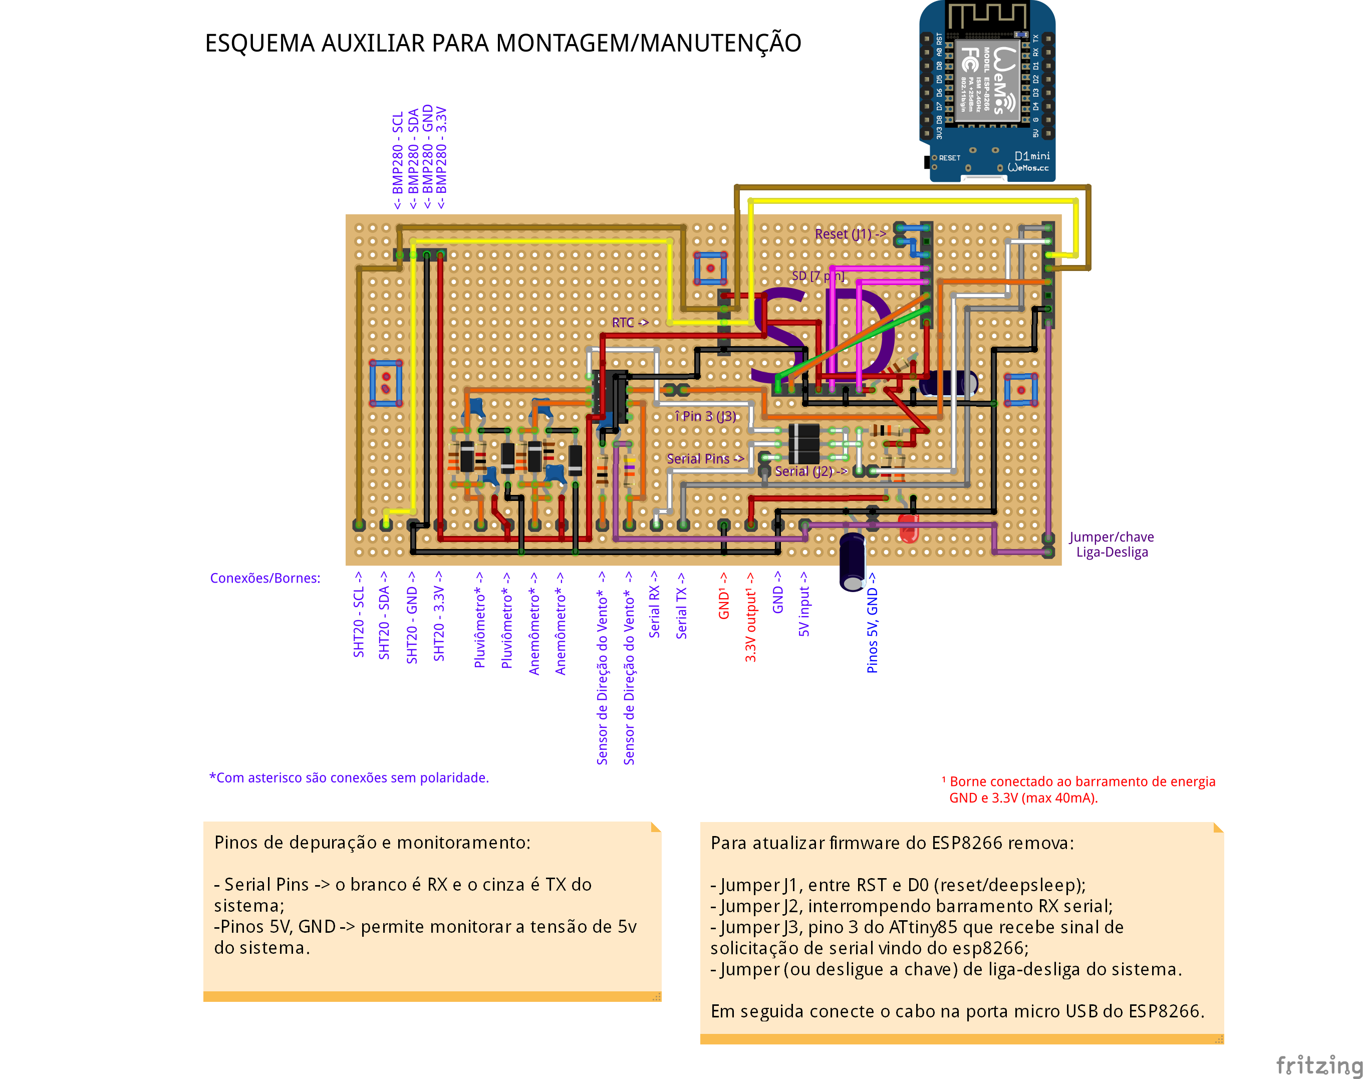
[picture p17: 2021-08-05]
weather-station/hardware/esquema-eletrico/rev 1 - Placa estação 1/Esquema elétrico auxiliar para exemplo de protoboard - rev3_bb_esp8266_out.png

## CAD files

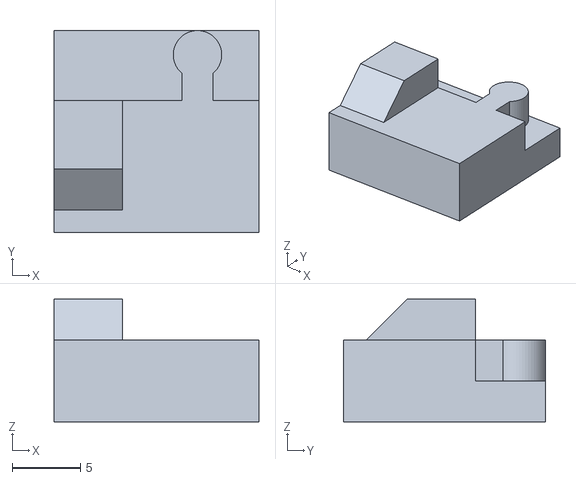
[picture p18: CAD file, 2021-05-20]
weather-station/hardware/Estuturas/caixa/Encaixe suporte controlador.stl
15.0 x 14.8 x 9.00

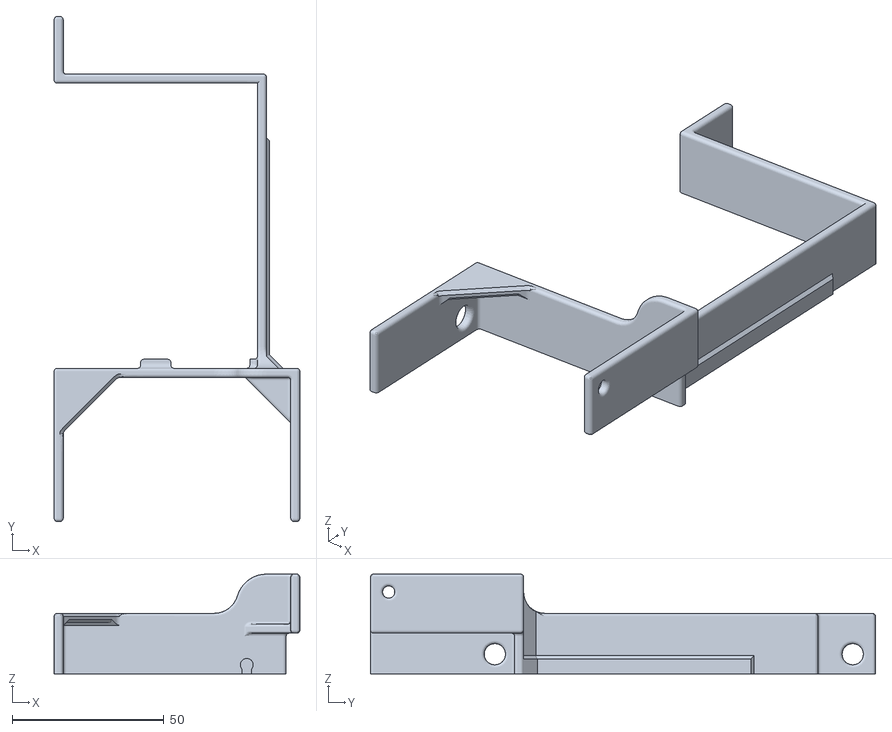
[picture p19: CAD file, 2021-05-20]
weather-station/hardware/Estuturas/caixa/Fixador bateria v2.5 - L.stl
81.0 x 166.5 x 32.9

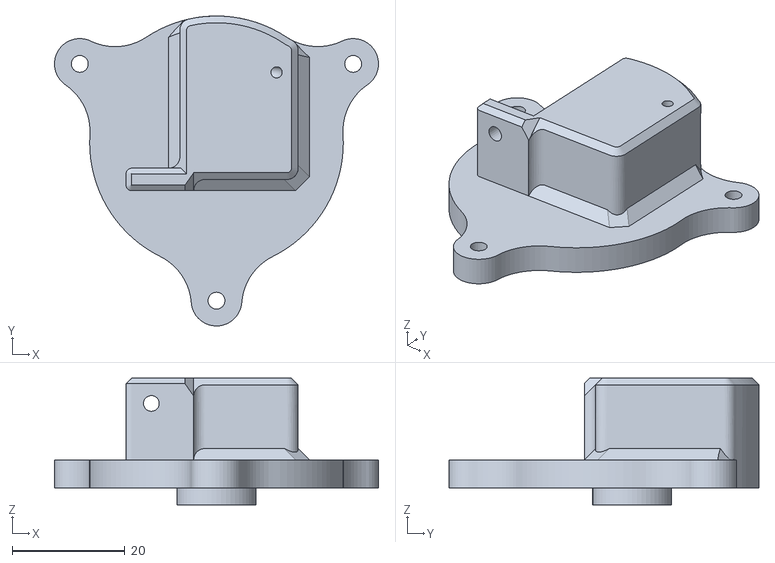
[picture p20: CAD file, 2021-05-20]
weather-station/hardware/Estuturas/caixa/Respirador_v1.stl
57.5 x 55.0 x 22.5

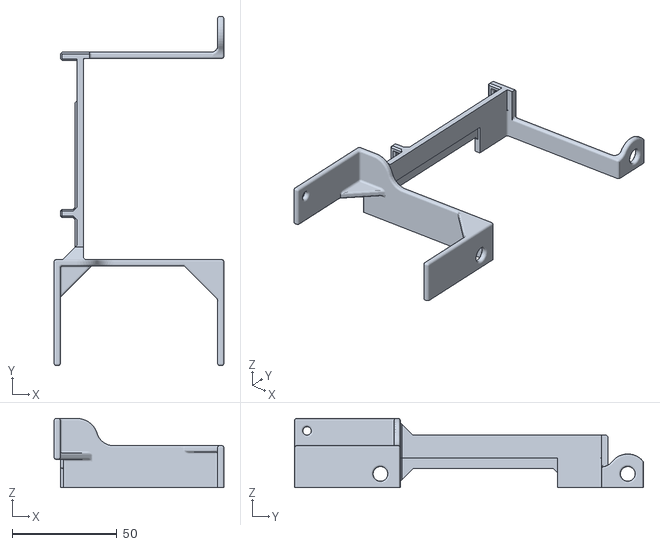
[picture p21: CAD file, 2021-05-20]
weather-station/hardware/Estuturas/caixa/Fixador bateria v2.5 - R.stl
81.0 x 166.5 x 32.9

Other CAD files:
Estuturas/estrutura_telhado/Parafuso m3 30mm.ipt
Estuturas/estrutura_telhado/barra roscada 100 mm m6.ipt
Estuturas/estrutura_telhado/caixa/encaixe suporte controlador L.ipt
Estuturas/estrutura_telhado/caixa/fixador bateria v2.5 - L.ipt
Estuturas/estrutura_telhado/caixa/fixador bateria v2.5.ipt
Estuturas/estrutura_telhado/caixa/respirador_v1.ipt
Estuturas/estrutura_telhado/pluviometro.ipt
Estuturas/estrutura_telhado/porca m6.ipt
Estuturas/estrutura_telhado/suporte sensores solares.ipt
weather-station/hardware/Estuturas/0070.1 - Abraçadeira U Vergalhão bitola 1 polegada 80mm rosca 1 quarto.ipt
weather-station/hardware/Estuturas/0070.2 - Abraçadeira suporte.ipt
weather-station/hardware/Estuturas/Alojamento do Sensor de Temperatura e Umidade/OldVersions/Parafuso m3 70mm.0008.ipt
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

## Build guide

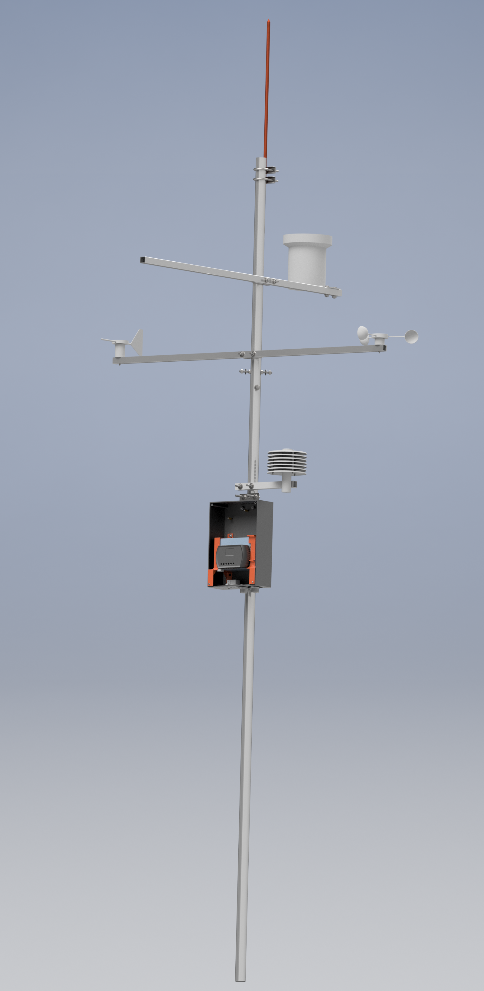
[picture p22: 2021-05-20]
weather-station/hardware/Estuturas/Montagem-1.png

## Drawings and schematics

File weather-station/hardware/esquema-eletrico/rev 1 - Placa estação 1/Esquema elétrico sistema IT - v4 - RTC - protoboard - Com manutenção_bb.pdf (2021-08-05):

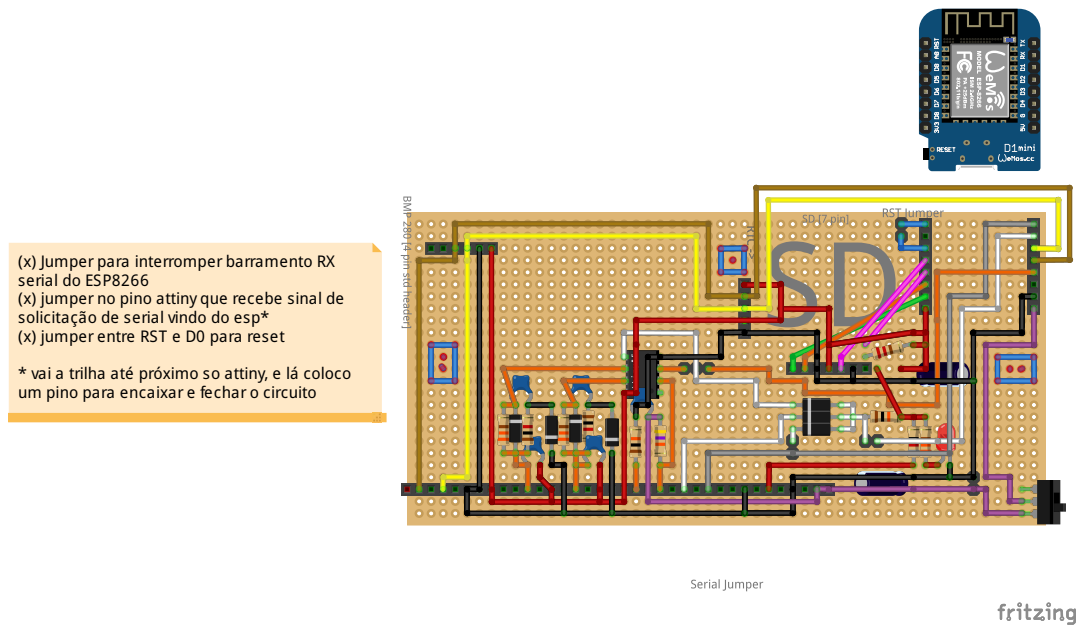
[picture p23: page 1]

(x) Jumper para interromper barramento RX
serial do ESP8266
(x) jumper no pino attiny que recebe sinal de
solicitação de serial vindo do esp*
(x) jumper entre RST e D0 para reset

* vai a trilha até próximo so attiny, e lá coloco
um pino para encaixar e fechar o circuito

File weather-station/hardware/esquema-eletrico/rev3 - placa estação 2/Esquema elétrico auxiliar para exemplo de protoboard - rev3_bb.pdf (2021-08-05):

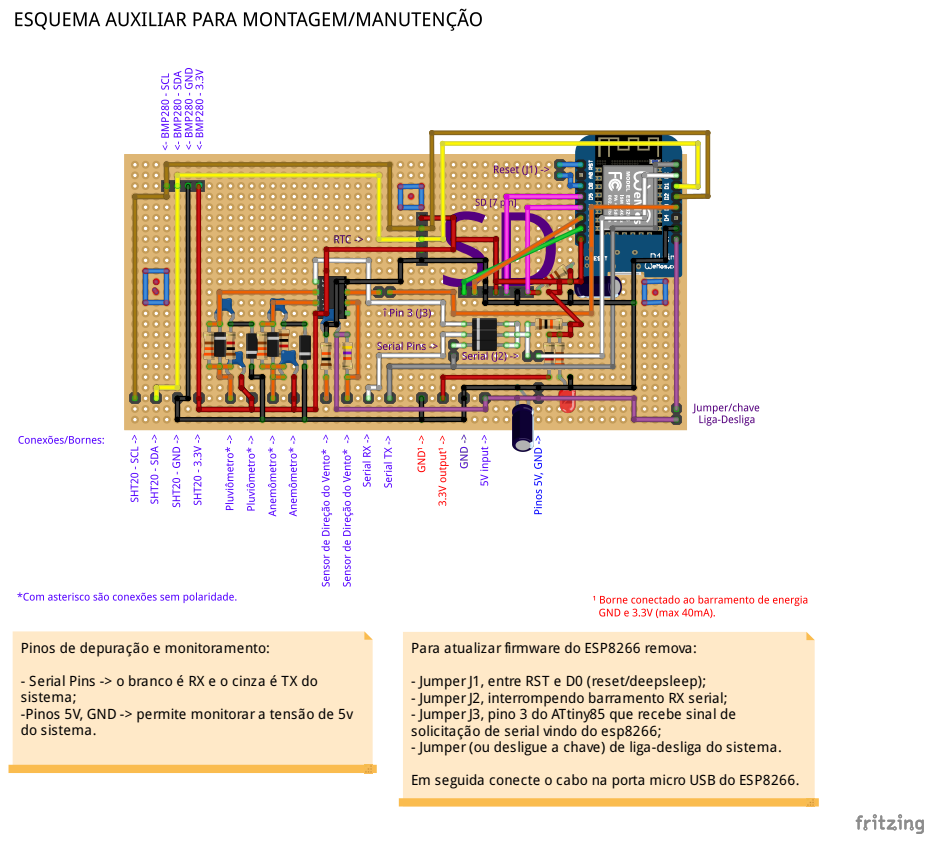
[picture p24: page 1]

Pinos de depuração e monitoramento:

Para atualizarfirmware do ESP8266 remova:

- Serial Pins -> o branco é RX e o cinza é TX do
sistema;
-Pinos 5V, GND -> permite monitorar a tensão de 5v
do sistema.

- JumperJ1, entre RST e D0 (reset/deepsleep);
- JumperJ2, interrompendo barramento RX serial;
- JumperJ3, pino 3 do ATtiny85 que recebe sinal de
solicitação de serial vindo do esp8266;
- Jumper(ou desligue a chave) de liga-desliga do sistema.

Em seguida conecte o cabo na porta micro USB do ESP8266.

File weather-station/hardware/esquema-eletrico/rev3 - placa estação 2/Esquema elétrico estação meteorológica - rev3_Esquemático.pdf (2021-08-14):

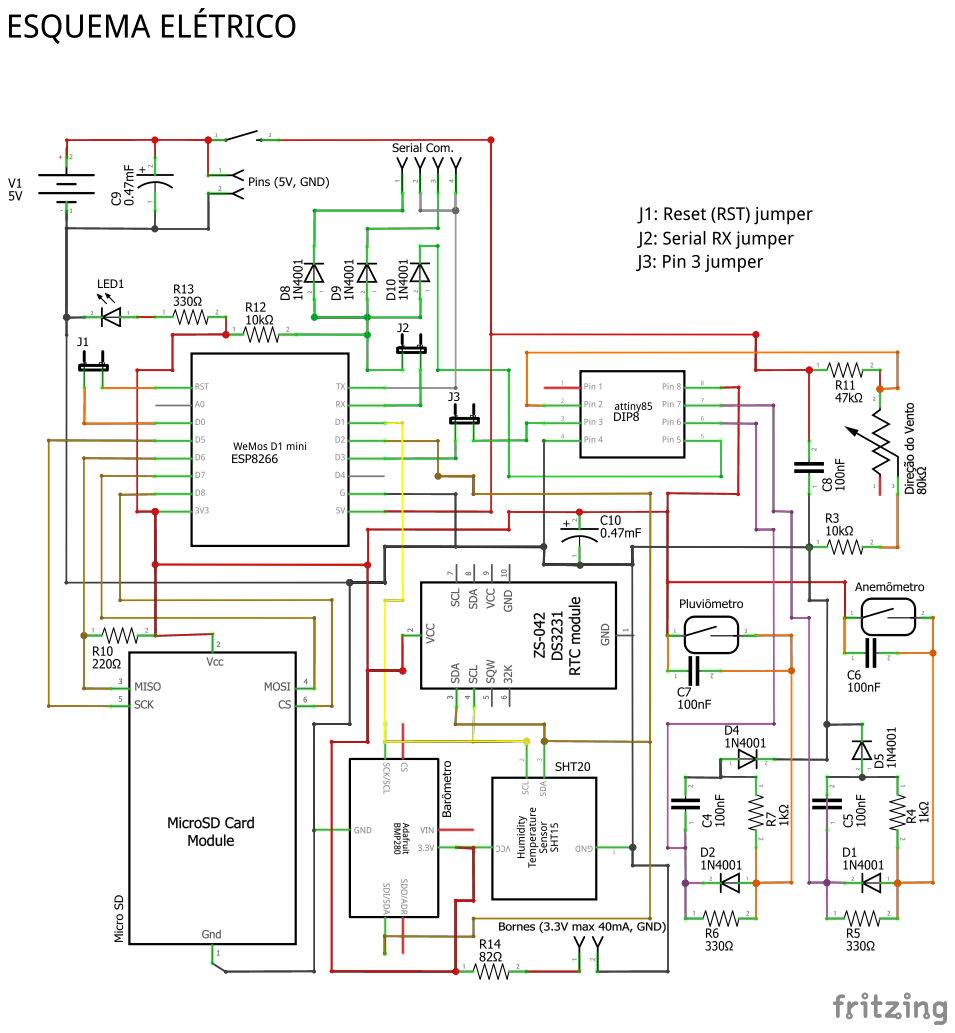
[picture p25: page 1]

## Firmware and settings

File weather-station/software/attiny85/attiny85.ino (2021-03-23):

/*****************************************************************
  * STATUS: all ok.
  * 
  * FIRMWARE DESCRIPTION
  * 
  * Version: 2.6 (20210202)
  * Developer: Romildo C Marques
  * E-mail: contato@romildo.me
  * 
  * OUTPUT DATA DESCRIPTION
  * 
  * The output data it's a CSV string:
  * "windDirection,wind_speed_kmh,mmOfRain*"
  * Example: "N,9.72,1.75*" = north wind, wind speed 9.72 km/h and 1.75 mm of rain. * is the end character.
  * 
  * // Wind Direction Output
  * //     EN    |    PT    | Output | Degrees
  * // North     | Norte    | N      | 0/360
  * // Northeast | Nordeste | NE     | 45
  * // East      | Leste    | E      | 90
  * // Southeast | Sudeste  | SE     | 135
  * // South     | Sul      | S      | 180
  * // Southwest | Sudoeste | SW     | 225
  * // West      | Oeste    | W      | 270
  * // Northwest | Noroeste | NW     | 315
  * 
  * ATENTION FOR THE HARDWARE LIMITATIONS
  * 
  * Pluviometer will be reset after 8000 mm of rain. The variable
  * pluviometer_reed_switch_count will be reset at 6400 commutations.
  * Becouse is  a unsigned int type and store a 2 byte value, is limited
  * to 65535. When the value is 6400 (8000 mm of rain), the variable
  * will be reset to 0.
  * 
  * I/O Ports Configuration
  * 
  * Reset ->                (Pin 1)
  * Wind Vane -> A3         (Pin 2)
  * Wemos signal in -> A1   (Pin 3)
  * GND ->                  (Pin 4)
  * Serial TX -> D0         (Pin 5)
  * Rain gauge -> PCINT1    (Pin 6)
  * Anemometer -> EI0       (Pin 7)
  * VCC ->                  (Pin 8)
  * 
*****************************************************************/

// SendOnlySoftwareSerial library and seting
#include <SendOnlySoftwareSerial.h>

// Library for pin change interrupt
#include <avr/interrupt.h>

// SendOnlySoftwareSerial seting
SendOnlySoftwareSerial mySerial(0); // Tx pin

// Constants
const float pi = 3.14159265; // Number PI
const int radius = 147;      // Anemometer radius in mm
const int period = 5000;     // anemometer periode of measurement

// Variables
int wemos_com_in = 0, // Wemos's communication input voltage
    last_wemos_com_in = 0; // Wemos's oldest communication input voltage
volatile unsigned int pluviometer_reed_switch_count = 0, // Commutation counter of rain gauge
    anemometer_switch_count = 0; // Commutation counter of anemometer
float anemometer_measurement = 0, pluviometer_measurement = 0;
unsigned long anemometer_last_time = 0;
String out; // String for serial data output

// Interrupt service routines
void anemometer_interrupt_count()
{
    anemometer_switch_count++;
}

ISR(PCINT0_vect)
{
    pluviometer_reed_switch_count++; // Increment volatile variable
}

/******************************************************************
 * This function returns the wind speed in Km/h, in float type
 * ***************************************************************/
float anemometer()
{
    float wind_speed_ms = 0, wind_speed_kmh = 0;
    int interrupts_counter = 0;
    unsigned int RPM = 0; // Revolutions per minute
    unsigned long interrupt_time = 0, last_interrupt_time = 0, start_time, time_while = 0;

    attachInterrupt(0, anemometer_interrupt_count, RISING);

    anemometer_switch_count = 0;
    interrupts_counter = 0;

    // The time when begin the period of read and count interrupts
    start_time = millis();
    time_while = start_time + 1;

    // Counts interruptions
    while (abs(time_while - start_time) <= period)
    {
        if (anemometer_switch_count > 0)
        {
            interrupt_time = millis();
            if (abs(last_interrupt_time - interrupt_time) > 9)
            {
                last_interrupt_time = interrupt_time;
                anemometer_switch_count--;
                interrupts_counter++;
            }
            else
            {
                anemometer_switch_count--;
            }
        }

        // delay to prevent problem with event like "time_while == last_interrupt_time" caused becouse of the high clock of ESP8266 with millis() limitation (only milliseconds is a low precision for this while loop)
        delay(1);

        // Read the time to the while conditions
        time_while = millis();
    }

    detachInterrupt(0);

    // Compute the RPM
    RPM = ((interrupts_counter)*60) / (period / 1000);

    // Compute wind speed in m/s
    wind_speed_ms = ((4 * pi * radius * RPM) / 60) / 1000;

    // Compute wind speed in km/h
    wind_speed_kmh = wind_speed_ms * 3.6;

    return wind_speed_kmh;
}

/******************************************************************
 * This function returns the wind direction of a wind vane sensor
 * 
  * // Wind Direction Output
  * //     EN    |    PT    | Output | Degrees
  * // North     | Norte    | N      | 0/360
  * // Northeast | Nordeste | NE     | 45
  * // East      | Leste    | E      | 90
  * // Southeast | Sudeste  | SE     | 135
  * // South     | Sul      | S      | 180
  * // Southwest | Sudoeste | SW     | 225
  * // West      | Oeste    | W      | 270
  * // Northwest | Noroeste | NW     | 315
 * ***************************************************************/
String wind_vane()
{
    const int n_samples = 35;             // n_samples reads for average
    unsigned int wind_vane_signal_sum = 0;         // Wind vane input signal sum
    float wind_vane_signal_average = 0;   // Wind vane input signal average
    String wind_vane_output;

    // 490ms of delay for n_samples samples
    for (int i = 0; i < n_samples; i++)
    {
        wind_vane_signal_sum = wind_vane_signal_sum + analogRead(A3);
        delay(14);
    }

    // Average
    wind_vane_signal_average = wind_vane_signal_sum / n_samples;

    wind_vane_signal_sum = 0;

    // Wind direction
    if (wind_vane_signal_average >= 971)
    {
        wind_vane_output.concat("NW");
    }
    else if (wind_vane_signal_average >= 926)
    {
        wind_vane_output.concat("W");
    }
    else if (wind_vane_signal_average >= 874)
    {
        wind_vane_output.concat("SW");
    }
    else if (wind_vane_signal_average >= 810)
    {
        wind_vane_output.concat("S");
    }
    else if (wind_vane_signal_average >= 732)
    {
        wind_vane_output.concat("SE");
    }
    else if (wind_vane_signal_average >= 636)
    {
        wind_vane_output.concat("E");
    }
    else if (wind_vane_signal_average >= 514)
    {
        wind_vane_output.concat("NE");
    }
    else if (wind_vane_signal_average >= 300)
    {
        wind_vane_output.concat("N");
    }
    else
    {
        wind_vane_output.concat("null");
    }

    return wind_vane_output;
}

void setup()
{
    // Rain gauge pin change interrupt setup
    GIMSK = 0b00100000; // turns on pin change interrupts
    PCMSK = 0b00000010; // turn on interrupts on pin PCINT1 = Pin 6

    mySerial.begin(9600);
    pinMode(A3, INPUT); // Wind vane input
    pinMode(A2, INPUT); // Wemos signal in
    pinMode(2, INPUT_PULLUP); // Anemometer attach interrupt input pin 0 = digital pin 2 = HW pin 7

    // Get the wind speed
    anemometer_measurement = anemometer();
    anemometer_last_time = millis();
}

void loop()
{
    
    // Get the wind speed every 10 seconds
    if (abs(millis() - anemometer_last_time) > 10000)
    {
        // Get the wind speed
        anemometer_measurement = anemometer();
        anemometer_last_time = millis();
    }

    // reset the pluviometer_reed_switch_count at 64000 (equals 8000 mm of rain)
    if (pluviometer_reed_switch_count >= 64000)
    {
        pluviometer_reed_switch_count = pluviometer_reed_switch_count - 64000;
    }

    // Read the analog pin 2 to detect if ESP8266 microcontroller requested data
    wemos_com_in = analogRead(A2);

    // When the call is LOW to HIGH
    // Check the value, if > or equals 2.2v and the oldest voltage value is < or equals 1.1V
    if ((wemos_com_in >= 450) && (last_wemos_com_in <= 220))
    {
        out = ""; // Clean the string

        // Concatenates the data on csv_output
        out.concat(String(wind_vane())); // Concatenates wind direction
        out.concat(","); // CSV comma
        out.concat(String(anemometer_measurement)); // Concatenates wind speed in km/h
        out.concat(",");
        pluviometer_measurement = (pluviometer_reed_switch_count * 0.5) * 0.25; // Rain measure
        out.concat(String(pluviometer_measurement)); // Concatenates rains measurement
        out.concat('*'); // Concatenates the end word of the string
        mySerial.print(out); // Sends the string via serial
        delay(100); // debouncing delay
    }
    // Stores the value of analog pin 2
    last_wemos_com_in = wemos_com_in;
}

/*
REFERENCES

Arduino Reference - attachInterrupt()
https://www.arduino.cc/reference/pt/language/functions/external-interrupts/attachinterrupt/

PLUVIÔMETRO ARDUINO COMO SENSOR DE CHUVA NA ESTAÇÃO METEOROLÓGICA
https://www.usinainfo.com.br/blog/pluviometro-arduino-como-sensor-de-chuva-na-estacao-meteorologica/

INDICADOR DE DIREÇÃO DO VENTO COM ARDUINO MELHORANDO SUA ESTAÇÃO METEOROLÓGICA
https://www.usinainfo.com.br/blog/indicador-de-direcao-do-vento-com-arduino-melhorando-sua-estacao-meteorologica/
*/

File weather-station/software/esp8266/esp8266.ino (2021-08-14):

/*******************************************************************************
 * STATUS: all ok.
 * 
 * CSV Description
 * 
 * 20201014222901,22.05,98612.67,21.80,80.23,N,9.72,1.75,1023,1023,1
 * date_and_time,bmp_temperature,bmp_pressure,sht_temperature,sht_humidity,wind_direction,anemometer(km/h),pluviometer,serial_sensor1,serial_sensor2,sd_status
 * 
 * STATUS SD Description
 * sd_status = 1, 2 ou 3
 * 1 = Ok
 * 2 = SD begin error
 * 3 = SD data write error
 *  
 * Need to download this library https://github.com/NorthernWidget/DS3231
****************/
// LIBRARIES
#include <ESP8266WiFi.h>     // ESP8266 Wi-Fi connection
#include <NTPClient.h>       // NTP time
#include <WiFiUdp.h>         // UDP communication for NTP time
#include <Wire.h>            // I2C connection/interface (BMP280, SHT20, RTC)
#include <Adafruit_Sensor.h> // BMP280
#include <Adafruit_BMP280.h> // BMP280
#include "DFRobot_SHT20.h"   // SHT20
#include <PubSubClient.h>    // MQTT
#include <SPI.h>             // SPI connection/interface (SD)
#include <SD.h>              // SD card SPI
#include <EEPROM.h>          // EEPROM library
#include <Time.h>            // Time library
#include <TimeLib.h>         // Libary for function days_interval(..)
#include <DS3231.h>          // RTC

// Wi-Fi parameters
const char *ssid = "REPLACE_WITH_YOUR_WIFI_SSID";
const char *password = "REPLACE_WITH_YOUR_WIFI_PASSWORD";

// MQTT broker parameters
const char *mqttServer = "yourMQTTserver.com"; // Server
const char *mqttUser = "yourMQTTuser";            // User
const char *mqttPassword = "yourMQTTpassword";    // Password
const int mqttPort = 12136;                   // Port
// const char *mqttTopicSub = "ws/esp0";          // Topic Weather Station 0 (teste)
const char *mqttTopicSub = "ws/esp1";          // Topic Weather Station 1, change the number 1 to the station number 1, 2, 3, etc

// MQTT
WiFiClient espClient;
PubSubClient client(espClient);

// NTP
WiFiUDP ntpUDP;
NTPClient timeClient(ntpUDP);

Adafruit_BMP280 bmp; // BMP280 I2C
DFRobot_SHT20 sht20; // SHT20 I2C
DS3231 Clock;        // RTC DS3231 I2C

// Constants
const int chipSelect = 15; // 15 = ESP8266 GPIO15 = Hardware Pin D8

// Variables
int sd_status = 0, wifi_connect_attempts = 0, mqtt_connect_attempts = 0, mqtt_client_state;

bool wifi_connection_status = true; // if false, not execute functions that maybe need connection

String csv_output,
    attiny_serial_data,
    esp8266_time,
    serial_sensor_data,
    file_name; // Only '8.3' file (8character.3character), like 1234578.csv or abcdefgh.txt
float bmp_temperature,
    bmp_pressure,
    sht_temperature,
    sht_humidity;
unsigned long begin_time = 0, // #DEBUG
    sleep_time = 0;

String serial_data_request(String sensor_id = "")
{
    int request_attempt = 0, comma_index, asterisk_index, sensor_id_length;
    unsigned long wait_for_request = 0;
    String received;
    String received_measurements;

    sensor_id_length = sensor_id.length();

    // Clear serial buffer
    if (Serial.available())
    {
        // Serial.println("Had in serial before requesting sensor_id " + sensor_id + " data:");
        while (Serial.available())
        {
            received.concat(Serial.read());
        }
        received = "";
    }

    // #DEBUG
    // Serial.print("Begin sensor_id data request: ");
    // Serial.println(millis());

    while (!Serial.available() && request_attempt < 5)
    {
        request_attempt++;

        // #DEBUG
        // Serial.print("Time on while for requesting sensor_id " + sensor_id + "data: ");
        // Serial.println(millis());
        // Serial.print("Serial request attempt: " + String(request_attempt));
        // Serial.println(request_attempt);

        delay(100);
        // Sensor id
        Serial.print(String(sensor_id) + '\n');
        // Serial.println();

        wait_for_request = millis();
        // while (((millis() - wait_for_request) < 2000) && !Serial.available())
        while ((abs(millis() - wait_for_request) < 2000) && !Serial.available())
        {
            // #DEBUG
            // Serial.print("Serial delay while, serial status: ");
            // Serial.println(Serial.available());

            delay(100);
        }
    }

    if (Serial.available())
    {
        // "id1,1000,850*" -> "sensor_id id, measurement"
        received = Serial.readStringUntil('\n');
        

        if (sensor_id.equals(received.substring(0, sensor_id_length)))
        {
            comma_index = received.indexOf(",");
            asterisk_index = received.indexOf("*");

            received_measurements = received.substring(comma_index + 1, asterisk_index);

            // DEBUG
            Serial.println("Received: " + received);
            Serial.println("Measurement: " + received_measurements);

            return received_measurements;
        }
    }
    else
    {
        // If not received, "snr" = Serial Not Received
        // received.concat(sensor_id);
        received_measurements.concat("snr,snr");

        // #DEBUG
        Serial.println("Serial unavailable snr code, sends: " + received_measurements);

        return received_measurements;
    }
}

/************************************************************
 * this function returns a String with the format:
 * YYYYMMDDhhmmss
 * YYYY = year
 * MM = month
 * DD = day
 * hh = hour
 * mm = minute
 * ss = second
 * *********************************************************/
String get_time_NTP()
{
    timeClient.begin(); // NTPClient Begin
    delay(100);

    String t;
    String formatted_time;
    unsigned long epochTime;
    int year, month, day;

    timeClient.update();
    epochTime = timeClient.getEpochTime();

    // Get time in format 17:12:36
    t = timeClient.getFormattedTime();

    // Get formated time struct
    struct tm *ptm = gmtime((time_t *)&epochTime);

    // Year
    year = ptm->tm_year + 1900;
    formatted_time.concat(String(year)); // ex: 2020

    // Month
    month = ptm->tm_mon + 1;
    if (month < 10)
    {
        formatted_time.concat("0");
        formatted_time.concat(String(month)); // 06
    }
    else
    {
        formatted_time.concat(String(month)); // 12
    }

    // Day
    day = ptm->tm_mday;
    if (day < 10)
    {
        formatted_time.concat("0");
        formatted_time.concat(String(day)); // 06
    }
    else
    {
        formatted_time.concat(String(day)); // 20
    }

    // t = 17:12:36
    formatted_time.concat(String(t.substring(0, 2))); // Hour 10
    formatted_time.concat(String(t.substring(3, 5))); // Minutes 10
    formatted_time.concat(String(t.substring(6)));    // Seconds

    return formatted_time;
}
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
